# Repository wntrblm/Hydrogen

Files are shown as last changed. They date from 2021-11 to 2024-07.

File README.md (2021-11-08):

# Winterbloom Hydrogen

Hydrogen is a precision buffered multiple for 1U Eurorack.

More details available at https://winterbloom.com/shop/hydrogen

## Repository layout

This repository contains the hardware design files and user guide for Hydrogen:

- **hardware/** contains the hardware design files for the mainboard and blank panel. These are all created using KiCAD.
- **user_guide/** contains the user's guide source files. These are written in Markdown and published using MkDocs.

## License and contributing

Hydrogen is open-source hardware and software, however, licensing a project like this is a little complicated. Please take a chance to review the [LICENSE](LICENSE.md) file.

We welcome contributions! Please read our [Code of Conduct](CODE_OF_CONDUCT.md) first.

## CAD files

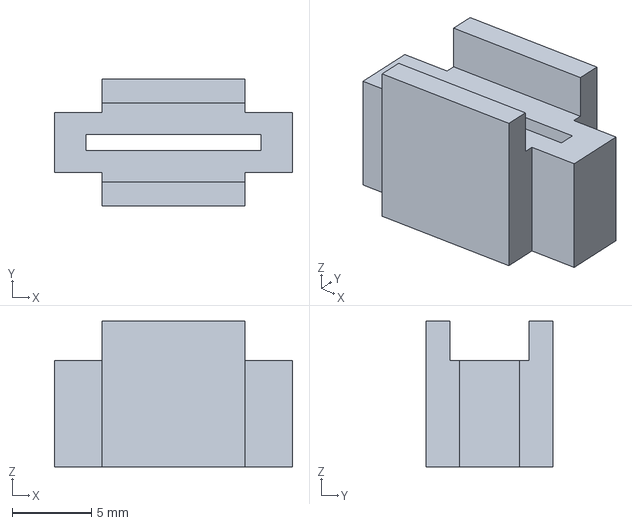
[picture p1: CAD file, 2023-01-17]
hardware/light-guide/light-guide.3mf
15.0 x 8.00 x 9.20 mm

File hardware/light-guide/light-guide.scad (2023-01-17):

difference() {
    linear_extrude(9.2) {
        difference() {
            union() {
                square([15, 3.8], center=true);
                square([9, 8], center=true);
            }
            square([11, 1], center=true);
        }
    }
    translate([0, 0, 9.2-2.5]) {
        linear_extrude(3) {
            square([18, 5], center=true);
        }
    }
}

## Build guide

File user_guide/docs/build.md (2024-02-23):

---
title: Kit build guide
---

# Hydrogen kit build guide

Welcome to the build guide for Hydrogen's DIY kit. We hope you have a great time putting this module together and a wonderful time using it.

Please **read all instructions** thoroughly before starting. If you have questions or run into trouble please reach out to us on [discord] or drop us an email at support@winterbloom.com.

Some soldering experience is helpful but not required. If it's your first time soldering we recommend reading through [Adafruit's guide to excellent soldering](https://learn.adafruit.com/adafruit-guide-excellent-soldering).

This build takes around **one hour** to complete.

[discord]: https://discord.gg/UpfqghQ

## Tools required

Before you begin, make sure that you've got:

-   Safety glasses. Yes, **really**. A pair like [these][safety glasses] are fine.
-   Proper ventilation, like this [small filtered fan](https://a.co/d/eUfPCRO).
-   A **temperature-controlled** soldering iron, like this [Hakko] or the [Pinecil]. It is very important to use a temperature-controlled iron, since unregulated irons can easily get hot enough to damage components. You should set your iron temperature based on your solder manufacturer's recommendations.
-   Solder. We recommend [Adafruit's SAC305 solder][adafruit solder] or [Kester 275 K100LD].
-   A small flat head screwdriver, like [this one][small screwdriver].

!!! question "Flux"
    We suggest using solder with "no clean" flux. If you use a different kind of flux, be sure to carefully clean the flux residue off based on the guidelines provided by the manufacturer of your solder. Take special care with the LEDs and potentiometers, as they can be damaged by water and flux cleaners.

[safety glasses]: https://a.co/d/dMXvPP6
[tweezers]: https://www.adafruit.com/product/422
[Hakko]: https://www.adafruit.com/product/1204
[Pinecil]: https://pine64.com/product/pinecil-smart-mini-portable-soldering-iron/
[adafruit solder]: https://www.adafruit.com/product/734
[Kester 275 K100LD]: https://www.kester.com/products/product/275-flux-cored-wire
[flux pen]: https://www.sra-solder.com/sra-312-no-clean-flux-pen-refillable
[small screwdriver]: https://lovemyswitches.com/2mm-flat-head-screwdriver-for-knob-set-screws/

## Kit contents

Your kit should contain the following items. If any are missing please email us at support@winterbloom.com.

<winter-image-map src="../images/kit.svg">
    <winter-image-map-item id="mainboard">Mainboard</winter-image-map-item>
    <winter-image-map-item id="panel">Front panel</winter-image-map-item>
    <winter-image-map-item id="jacks">1/8" jacks (10)</winter-image-map-item>
    <winter-image-map-item id="nuts">Hex nuts for the 1/8" jacks (10)</winter-image-map-item>
    <winter-image-map-item id="power-header">Eurorack power header (1)</winter-image-map-item>
    <winter-image-map-item id="rubber-bands">Rubber bands (2)</winter-image-map-item>
    <winter-image-map-item id="light-blocker">Light blocker</winter-image-map-item>
</winter-image-map>

- (1) Mainboard
- (1) Front panel
- (10) 1/8" jacks
- (10) Hex nuts for the 1/8" jacks
- (1) Eurorack power header
- (2) Rubber bands
- (1) Light blocker

!!! fairy "Light blocker"
    Older kits include a little plastic square for the light blocker along with a glue dot, newer kits include a 3d-printed light blocker. The older one is pictured here.

## Soldering the power header

Your first task is to place and solder the power header to the mainboard.

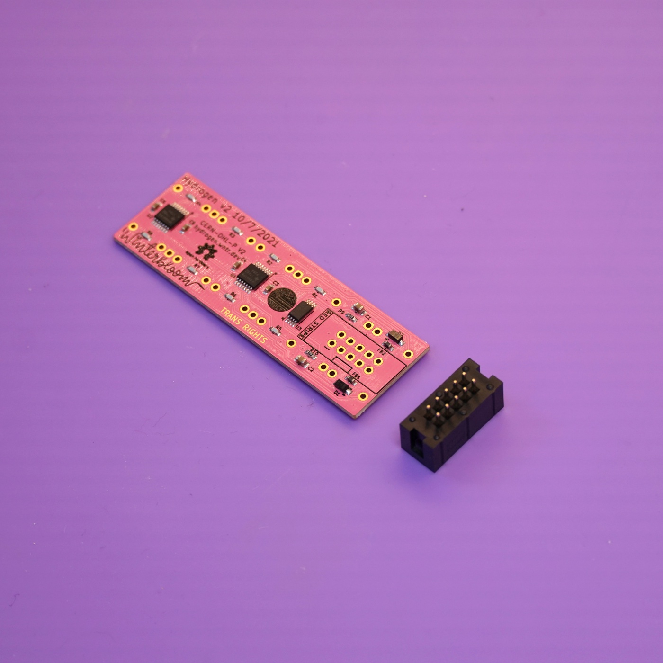
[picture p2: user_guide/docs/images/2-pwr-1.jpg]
The mainboard and power header


Place the power header onto the back side of the mainboard, being careful to align the notch in the header with the drawing on the board. The power header fits snugly, so you might have to give it a little pressure to push it all the way in.

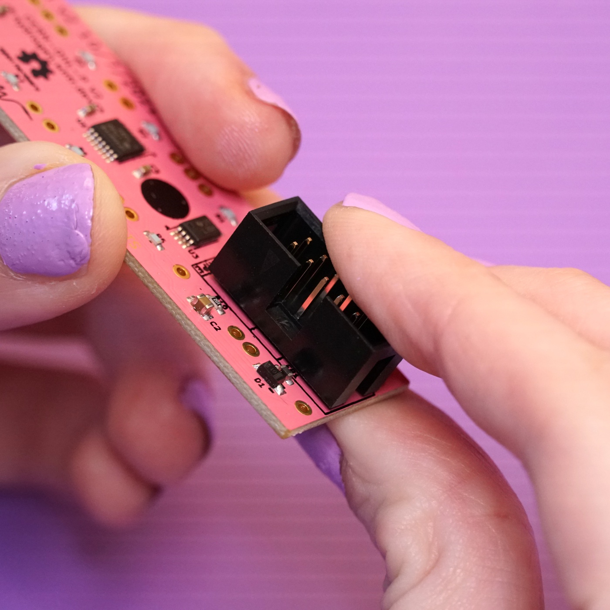
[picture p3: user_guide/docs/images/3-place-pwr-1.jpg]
The power header placed on to the mainboard


Flip the board over to the front side and solder the header's 10 pins. It's important to **avoid touching the LEDs** with your iron, as it could melt and destroy the LEDs. Also, take care not to put too much solder on these joints as it could make it difficult to place the jacks.

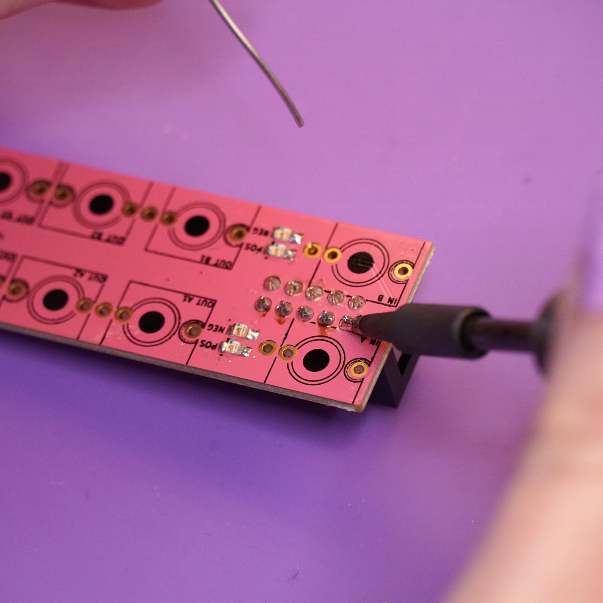
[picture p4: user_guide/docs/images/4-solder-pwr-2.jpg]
The power header being soldered to the mainboard


## Placing the jacks

Next up is placing the ten jacks on the front side of the mainboard.

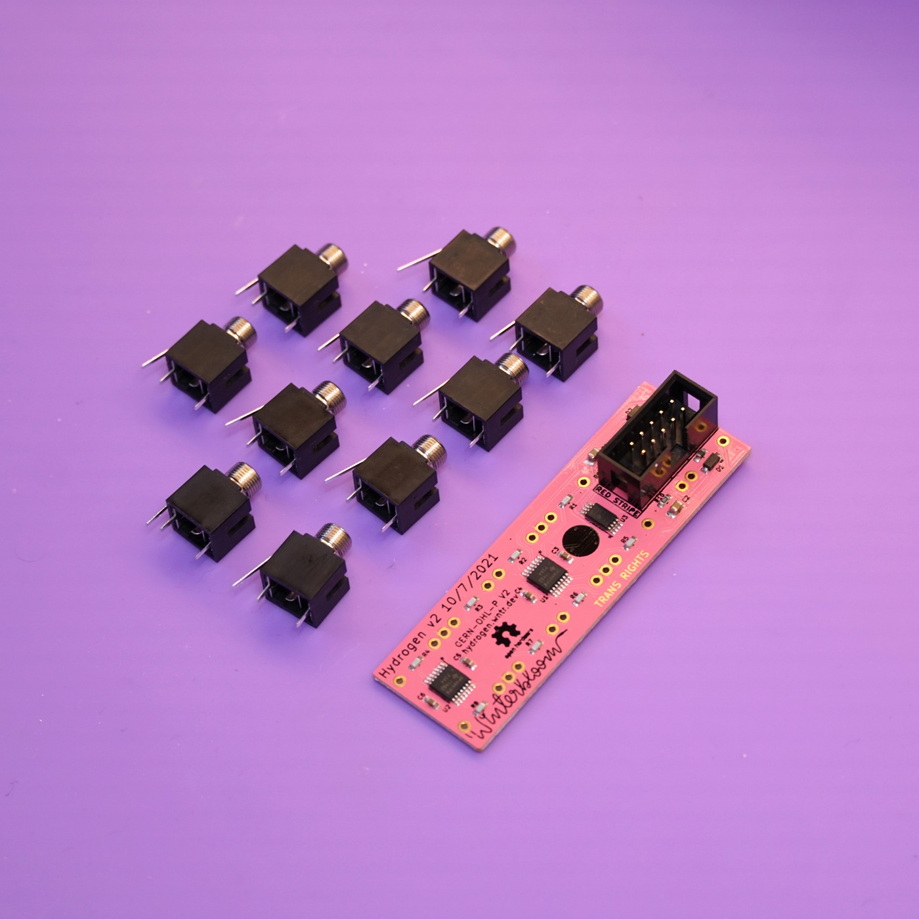
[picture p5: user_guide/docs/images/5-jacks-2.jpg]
The jacks and the mainboard


The two jacks near the power header are placed according to the drawing on the board, with the third, bendy leg going into the adjacent hole.

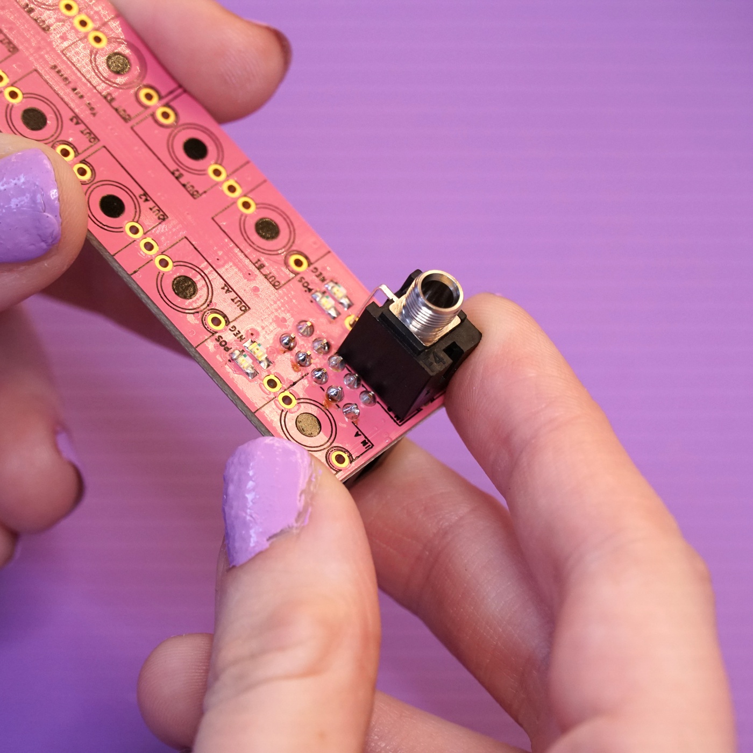
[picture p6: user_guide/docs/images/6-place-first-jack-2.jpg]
The first jack placed on the front side of the mainboard, over the place labeled "In B"


The other jacks are a bit trickier. Start by placing the jack for `Out B1` in the **same** orientation as the first two.

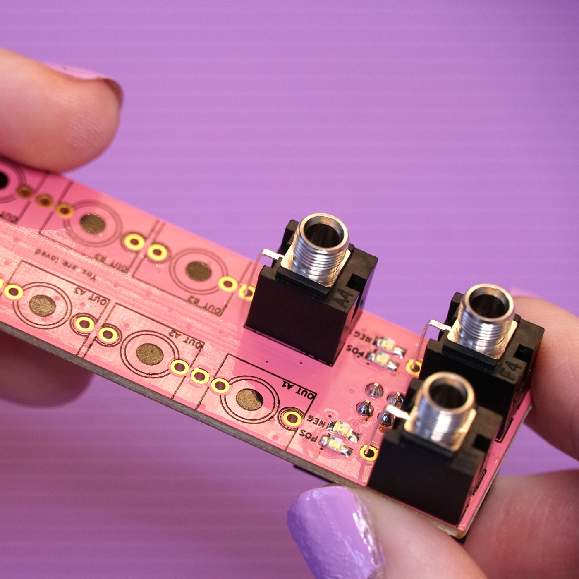
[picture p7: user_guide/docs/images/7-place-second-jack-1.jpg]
The third jack placed on the front side of the mainboard, over the place labeled "Out B1"


Then, place the jack for `Out B2` in the **opposite** orientation and place the third leg into the **same** hole as the adjacent jack's third leg.

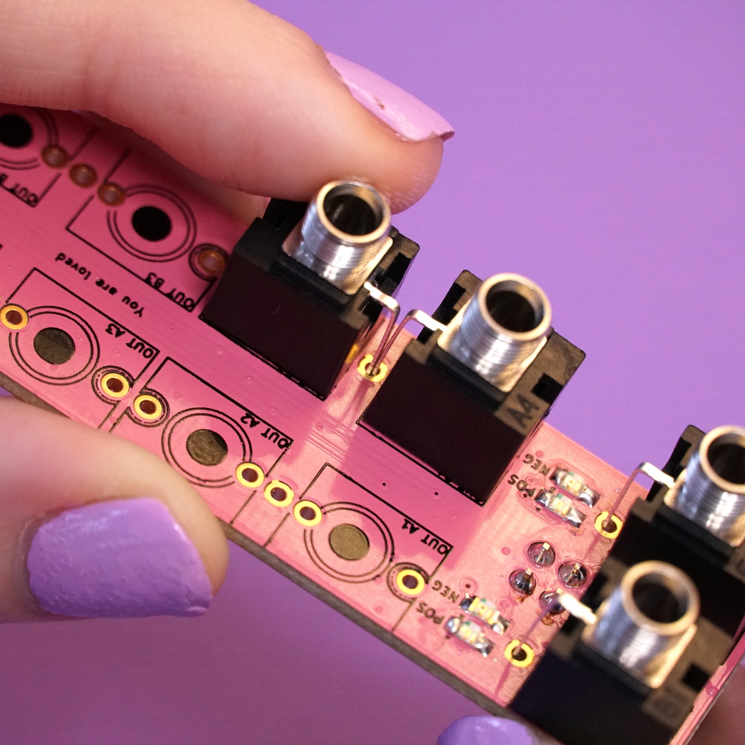
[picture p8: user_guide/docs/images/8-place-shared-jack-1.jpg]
The fourth jack placed on the front side of the mainboard, over the place labeled "Out B2". It is facing the opposite direction of the "Out B1" jack and is sharing a hole with it


The jacks for `Out B3` and `Out B4` follow the same pattern - they are placed in opposite orientations and share a single hole for both of their third legs.

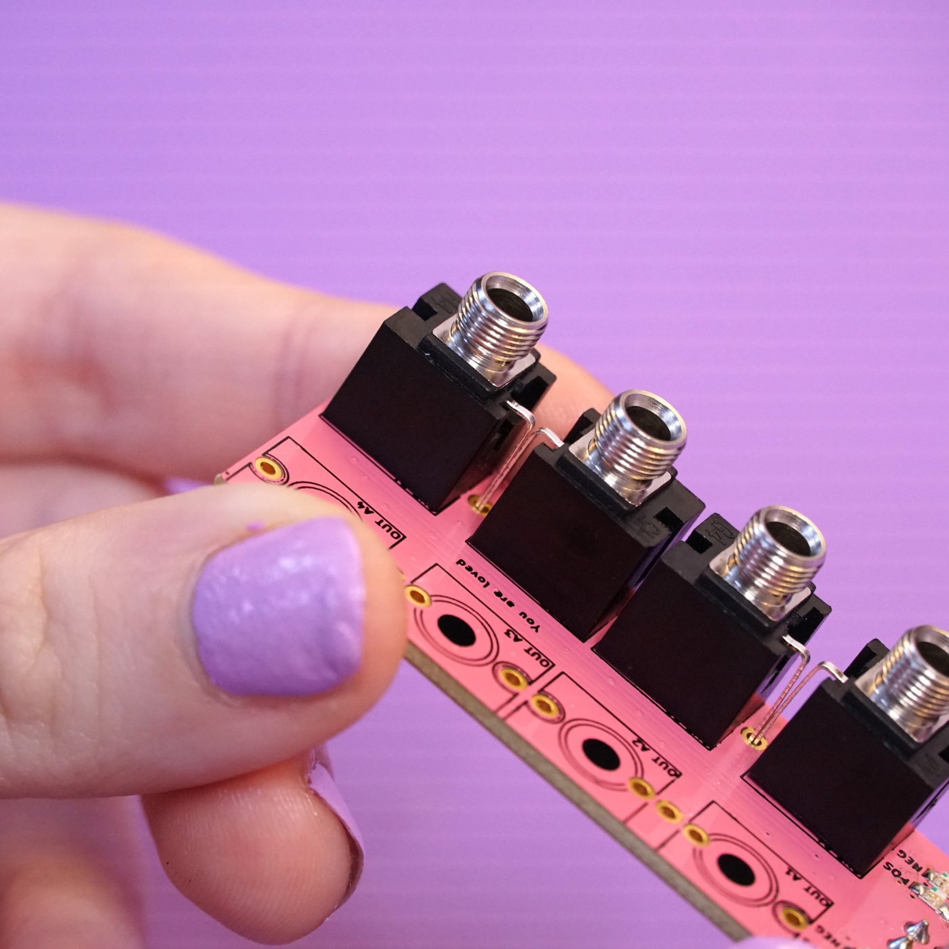
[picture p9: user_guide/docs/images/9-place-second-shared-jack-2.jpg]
The fifth and sixth jack placed on the front side of the mainboard over the places labeled "Out B3" and "Out B4" and are placed in the same way as the previous two


Repeat the same process to place the jacks for outs `A1`, `A2`, `A3`, and `A4`.

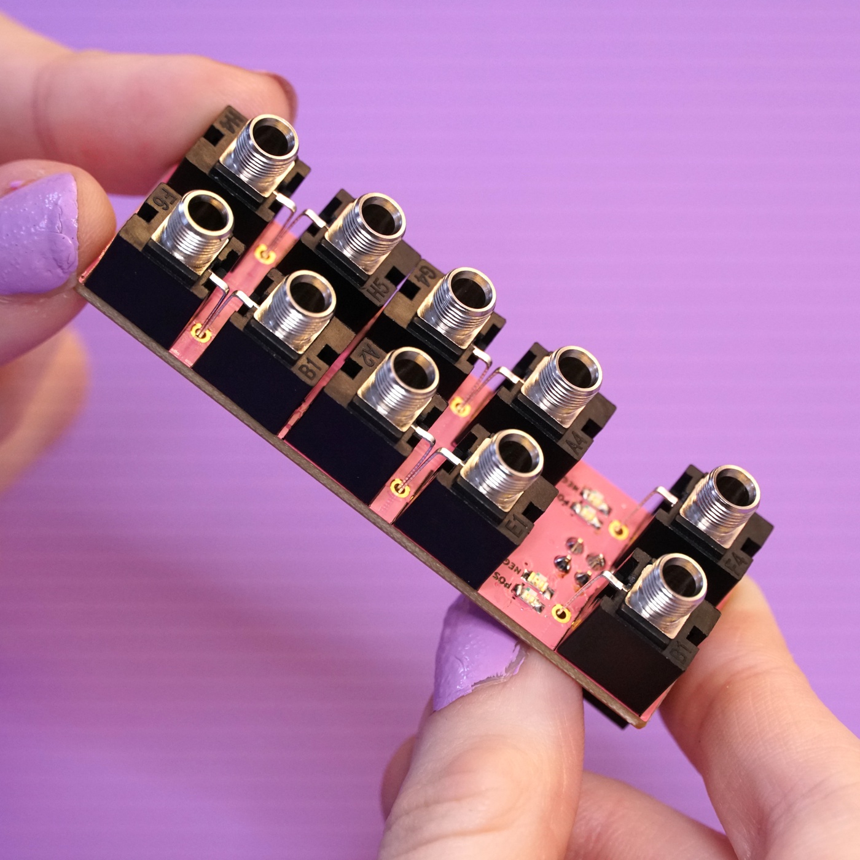
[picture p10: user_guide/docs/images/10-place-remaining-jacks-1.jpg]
The remaining jacks placed in the same way as the previous ones


## Using the front panel as a jig

Since the jacks need to peek through the front panel, you can use it as a jig to make sure everything stays in the right place while soldering. Carefully line up the front panel's holes with the jacks and push the front panel on. Then, use the two rubber bands to temporarily hold the front panel on while you're working on it. You'll need to double over the rubber band to get it tight. Put the other rubber bands on the opposite side of the module so that everything is held down snugly.

<winter-carousel>
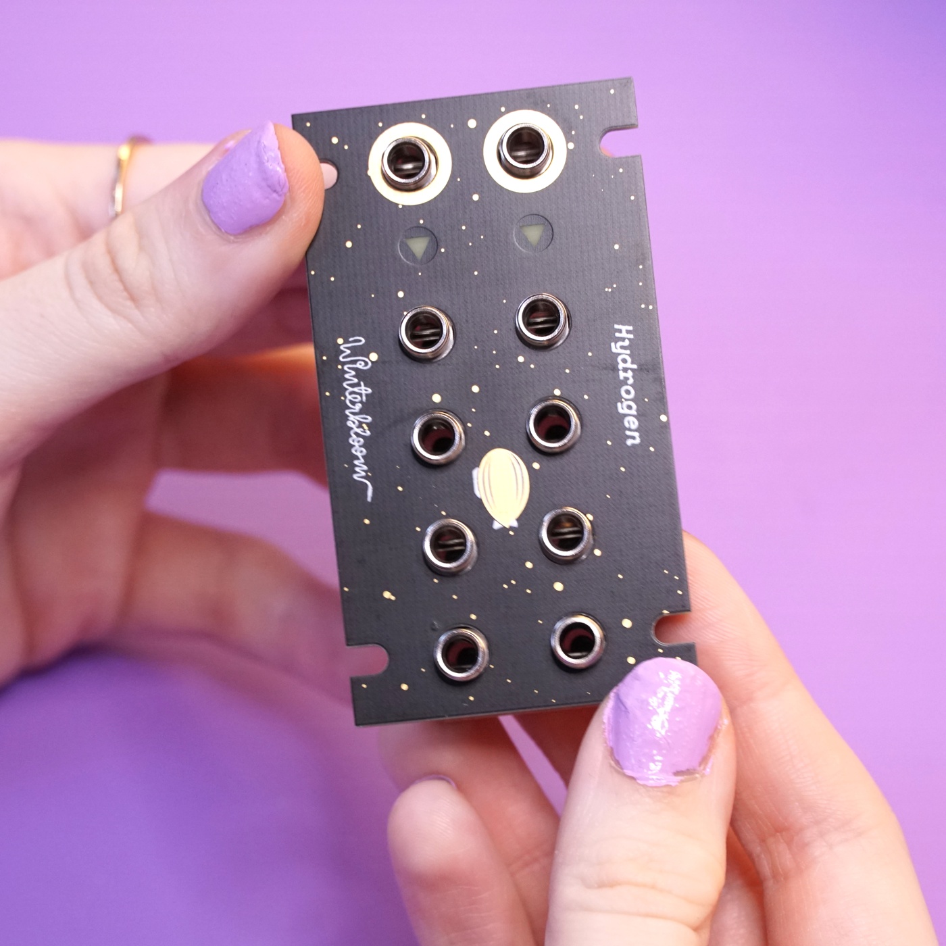
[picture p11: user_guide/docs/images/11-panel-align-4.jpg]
The front panel placed over the jacks
    
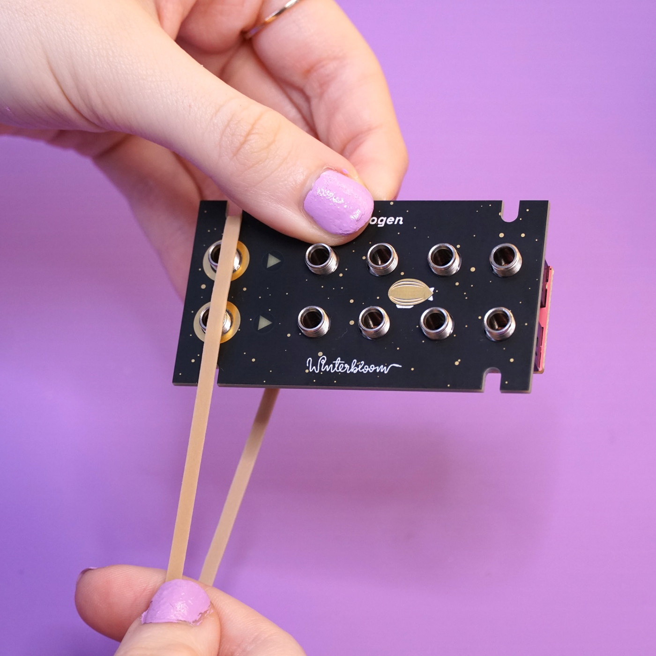
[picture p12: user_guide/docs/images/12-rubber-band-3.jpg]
A rubber band being pulled taught over one side of the module
    
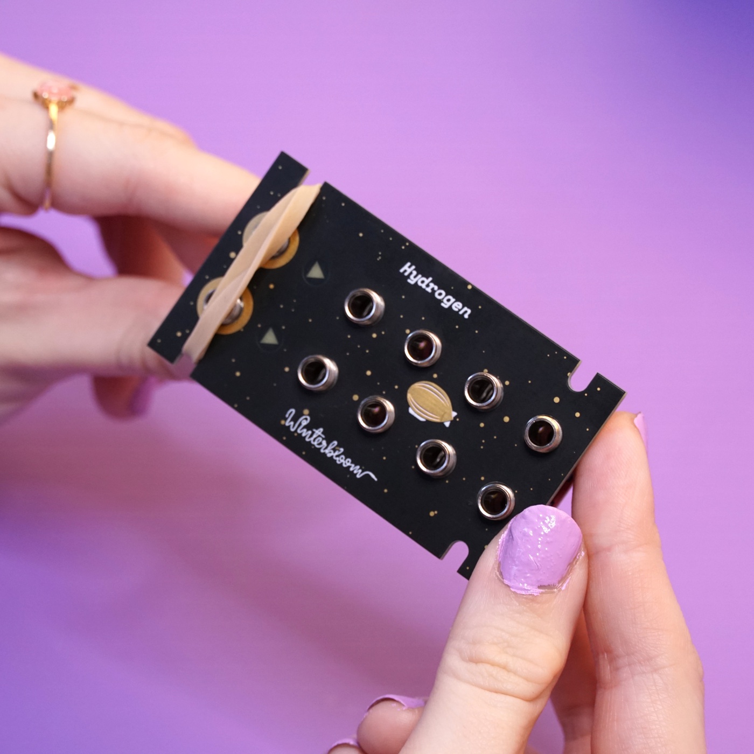
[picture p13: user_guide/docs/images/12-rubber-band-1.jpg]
The same rubber band doubled over and holding the front panel onto the module
    
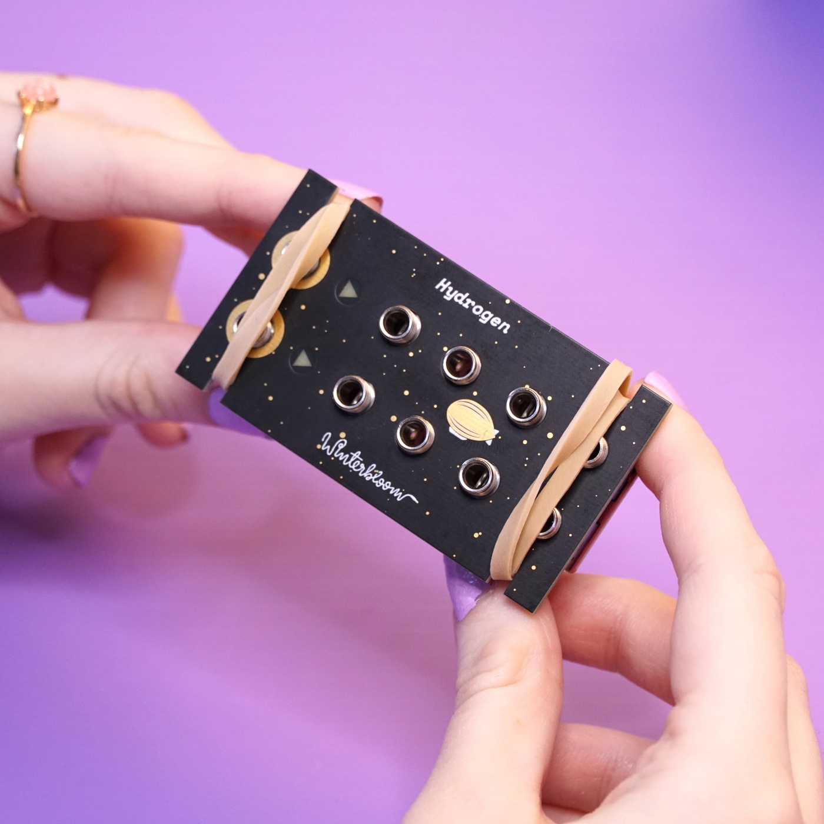
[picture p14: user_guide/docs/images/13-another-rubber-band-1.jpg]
Another rubber band has been placed on the other side of the module, firmly holding everything together
    
</winter-carousel>

## Soldering the jacks

With everything held in place, you can now flip the module over and solder all of the jacks in place. As you go, take a moment now and then to check that everything is flush with the panel and mainboard.

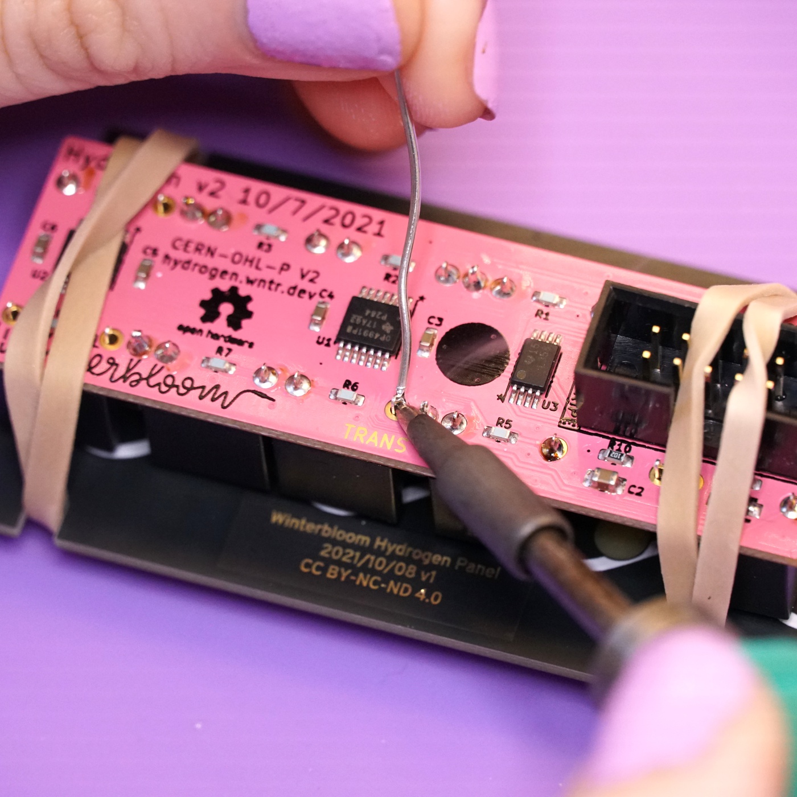
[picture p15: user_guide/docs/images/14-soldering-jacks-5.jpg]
The back side of the board is shown where one of the holes for the jacks is being soldered


Once you've got most of the soldering done, you can move the rubber bands out of the way to get to the holes that they were covering up. You won't need the rubber bands again after this step, so feel free to give those a new purpose in life somewhere else.

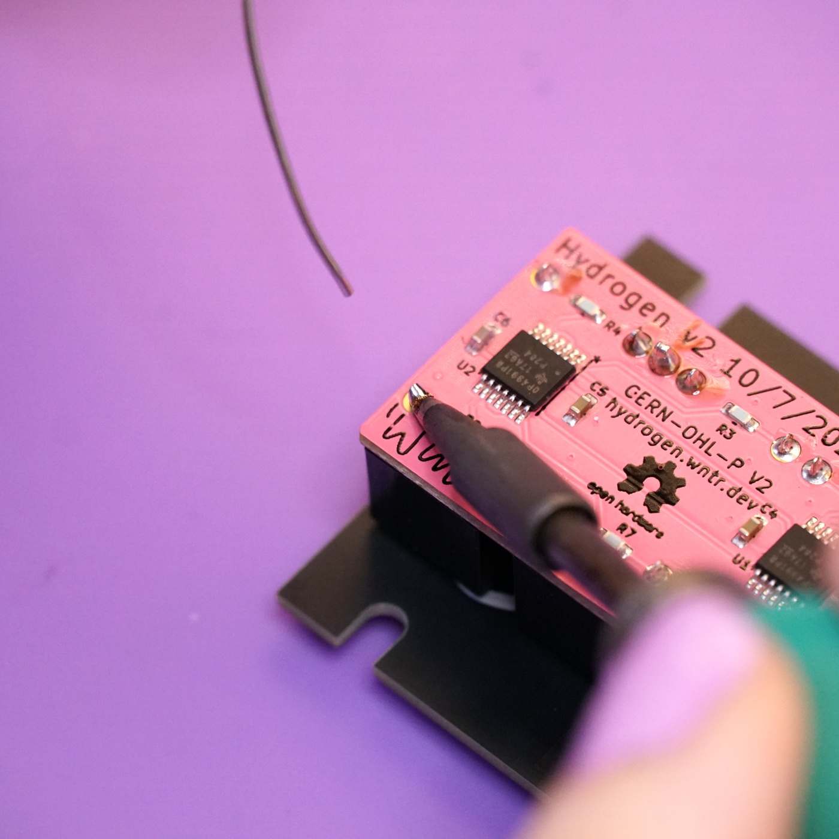
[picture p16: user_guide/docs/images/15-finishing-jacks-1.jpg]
The back side of the board is shown with the last hole for the jacks being soldered


## Placing the light blocker

Because the LEDs for Hydrogen's two channels are so close together, a small light blocker is used to keep them from bleeding into each other. There are **two versions** of the light blocker out there:

* The **older** kits come with a simple plastic square and a glue dot. The instructions below are for this version.
* The **newer** kits come with a 3d-printed light blocker. You don't need to glue this one in place, just place it in-between the jacks with the **flat side** facing upwards. The faceplate will hold it in place.

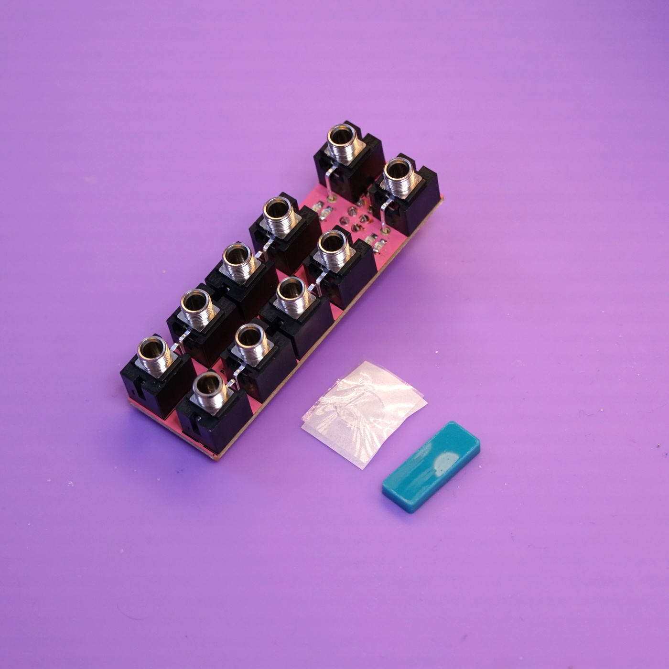
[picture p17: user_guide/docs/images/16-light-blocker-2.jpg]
The mainboard, the glue dot, and the light blocker


Prepare the glue dot by peeling off the white paper. Don't remove the clear film yet.

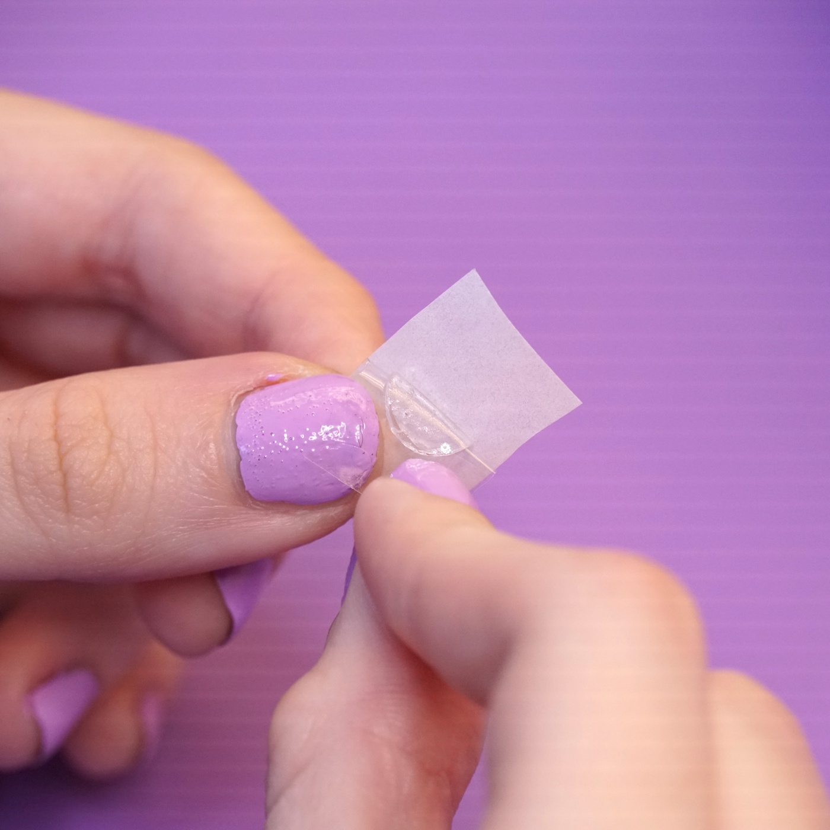
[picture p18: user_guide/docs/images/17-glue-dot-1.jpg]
The glue dot being peeled away from the white paper on one side of it


Place the exposed side of the glue dot to the upper end of the long side of the light blocker and remove the plastic film.

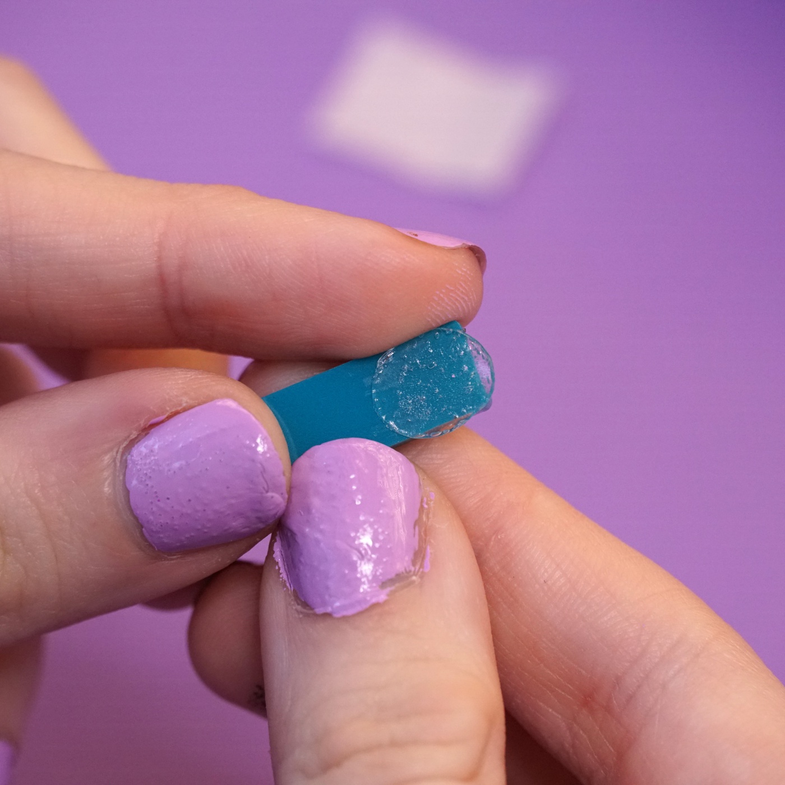
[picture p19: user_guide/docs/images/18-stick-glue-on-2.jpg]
The light blocker with the glue dot attached to one side of it


Place the light blocker between the two sets of LEDs and stick the end with the glue dot against one of the jacks. The light blocker doesn't need to be perfectly straight.

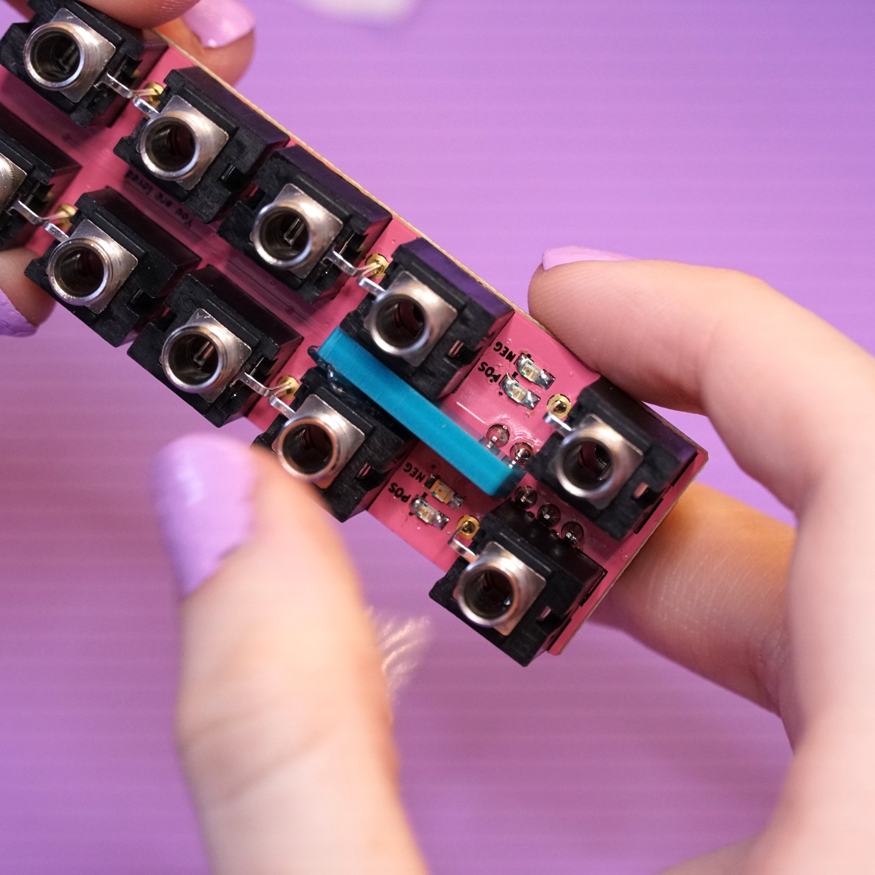
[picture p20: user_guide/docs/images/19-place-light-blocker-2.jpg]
The front side of the mainboard with the light blocker placed between the two sets of LEDs


## Putting the panel on

The last step it to place Hydrogen's lovely panel on and secure it with the hex nuts. You don't need to over-tighten the hex nuts, finger-tight is fine.

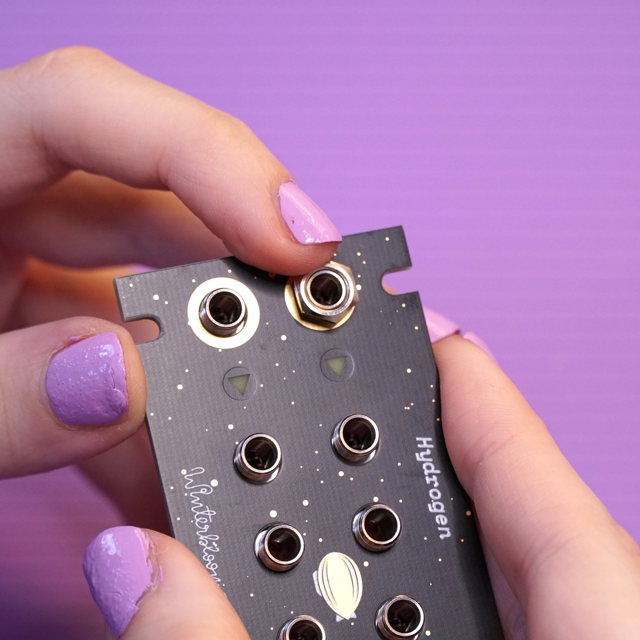
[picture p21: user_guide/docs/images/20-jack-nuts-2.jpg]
The module with the panel placed and one of the jack nuts being tightened in place


## All done

Congratulations! You've finished your very own Hydrogen!

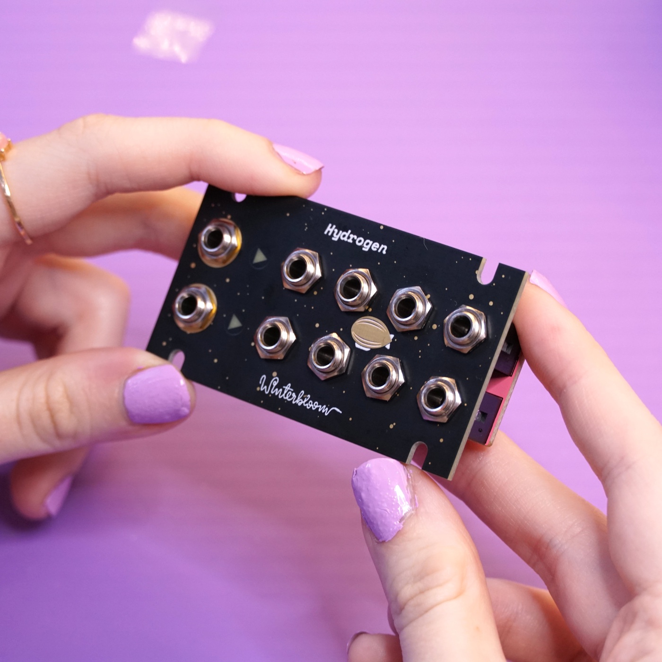
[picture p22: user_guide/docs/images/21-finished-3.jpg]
The compeleted module


Now that it's all put together go check out the [User's Guide](index.md) and please show us your work by tweeting at [@wntrblm](https://twitter.com/wntrblm) or tagging [@wntrblm](https://instagram.com/wntrblm) in your instagram post.

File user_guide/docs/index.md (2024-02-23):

# Hydrogen user guide

[Hydrogen](https://winterbloom.com/shop/hydrogen) is a 1U precision, two channel, 1-to-4 buffered multiple.

[TOC]

## Specifications

* Available [assembled](https://winterbloom.com/shop/hydrogen) or as a [kit](https://winterbloom.com/shop/hydrogen-kit)
* `1U` & `14 HP`
* `+12v @ 20mA`, `-12v @ 20mA`
* `22mm` deep
* Two channels
* Each channel has four buffered outputs
* Second channel normaled to the first so it can be used as a 1-to-8 buffered multiple.
* [ModularGrid page](https://www.modulargrid.net/e/winterbloom-hydrogen)

## Getting support and help

We want you to have a wonderful experience with your module. If you need help or run into problems, please reach out to us. [Email] is the best way for product issues, whereas [Discord] and [GitHub][github issues] are great for getting advice and help on how to customize your module.

-   Send us [an email][email]
-   File a bug [on GitHub][github issues]
-   Reach out on the [Discord][discord]

[github issues]: https://github.com/wntrblm/Neptune/issues
[discord]: https://discord.gg/UpfqghQ
[email]: mailto:support@winterbloom.com

## Installing the module

To install this into your Eurorack setup, connect a Eurorack power cable from your power supply to the back of the module. **Note that even though there's a keyed power connector on the module, double check that the red stripe is on the side labeled `red stripe`!** Once you've connected the power cable, secure your module to your rack rails using screws.

## Using the module

Hydrogen has two independent channels with four buffers. Each channel's input is on the left and the four buffered outputs follow on the right. The LEDs in between will glow blue for positive signals, red for negative signals, and purple for audio signals.

Illustration of using Hydrogen's two channels independently

Additionally, if nothing is connected to the second channel's input then the first channel's input is used. This allows you to use Hydrogen as a single channel one-to-eight buffer.

Illustration of using Hydrogen as a single channel, eight output buffer

That's pretty much it! ✨

## Open source hardware & software

Hydrogen is completely open source and hacking is encouraged.

The [hardware designs](https://github.com/wntrblm/Hydrogen/tree/main/hardware) are available under the permissive [CERN-OHL-P v2](https://cern-ohl.web.cern.ch/) and is designed using [KiCAD](https://kicad.org/) which is free and open-source. You can open the hardware files using KiCAD or you can [check out a PDF of the schematic](https://github.com/wntrblm/Hydrogen/tree/main/hardware/board/board.pdf).

Open Source Hardware Association mark Helium is [certified open source hardware](https://certification.oshwa.org/us002070.html)

## Warranty, disclaimers, and limits

Modules purchased from Winterbloom have a warranty of six months from the date of purchase. This warranty covers any manufacturing defects in the module. It does not cover damage from due to incorrect handling, storage, or power, overvoltage events, or modifications.

Please [contact us](mailto:support@winterbloom.com) if you are experiencing issues with your module. Modules returned under warranty will either be refunded, replaced, or repaired at our discretion. You will be responsible for the cost of returning the module to Winterbloom.

Because Eurorack has a vast number of possible combinations of power supplies, modules, cases, and accessories, it is impossible for us to guarantee compatibility with every possible configuration. We make a reasonable effort to test modules with several power supplies, cases, and other modules.

We encourage tinkering, however, we will not refund, repair, or replace any products that have been modified.

We have stress tested Hydrogen under the following conditions. These are provided for reference only; we do not guarantee that that the module will function under these conditions.

* Continuous run time: at least 48 hours
* Overvoltage from power supply: at least `±18 volts`
* Reverse voltage from power supply: at least `±18 volts`
* Undervoltage from power supply: as low as `±6 volts`
* Over and under voltage on inputs: at least `±12 volts`
* Outputs shorted together: at least 30 minutes
* Outputs shorted to ground: at least 30 minutes

## Acknowledgments and thanks

Hydrogen would not be possible without the support of Winterbloom's incredible community, the Trans Synth Discord, and Noise Engineering.

[discord]: https://discord.gg/UpfqghQ

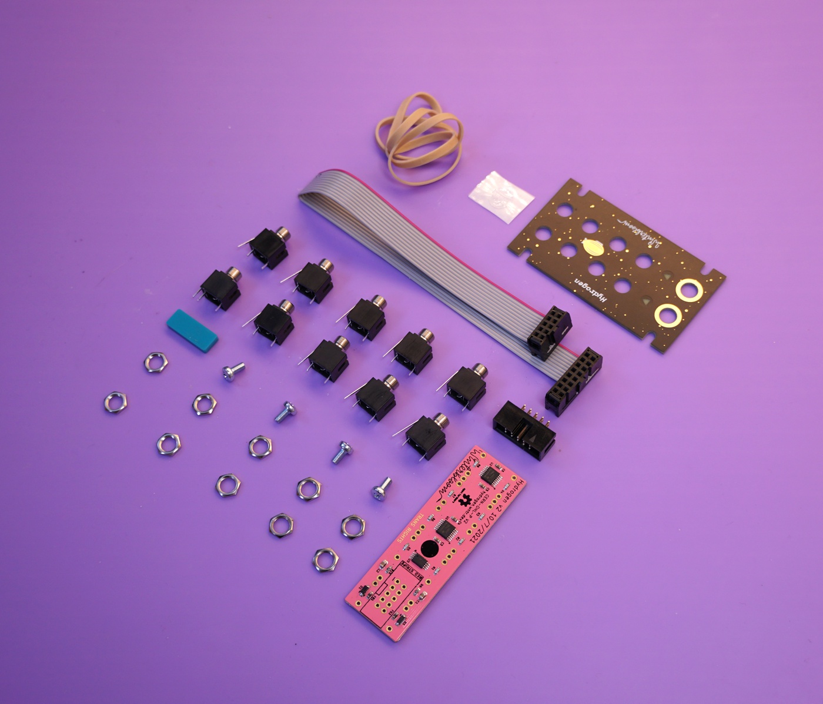
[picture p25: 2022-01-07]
user_guide/docs/images/1-kit-1.jpg

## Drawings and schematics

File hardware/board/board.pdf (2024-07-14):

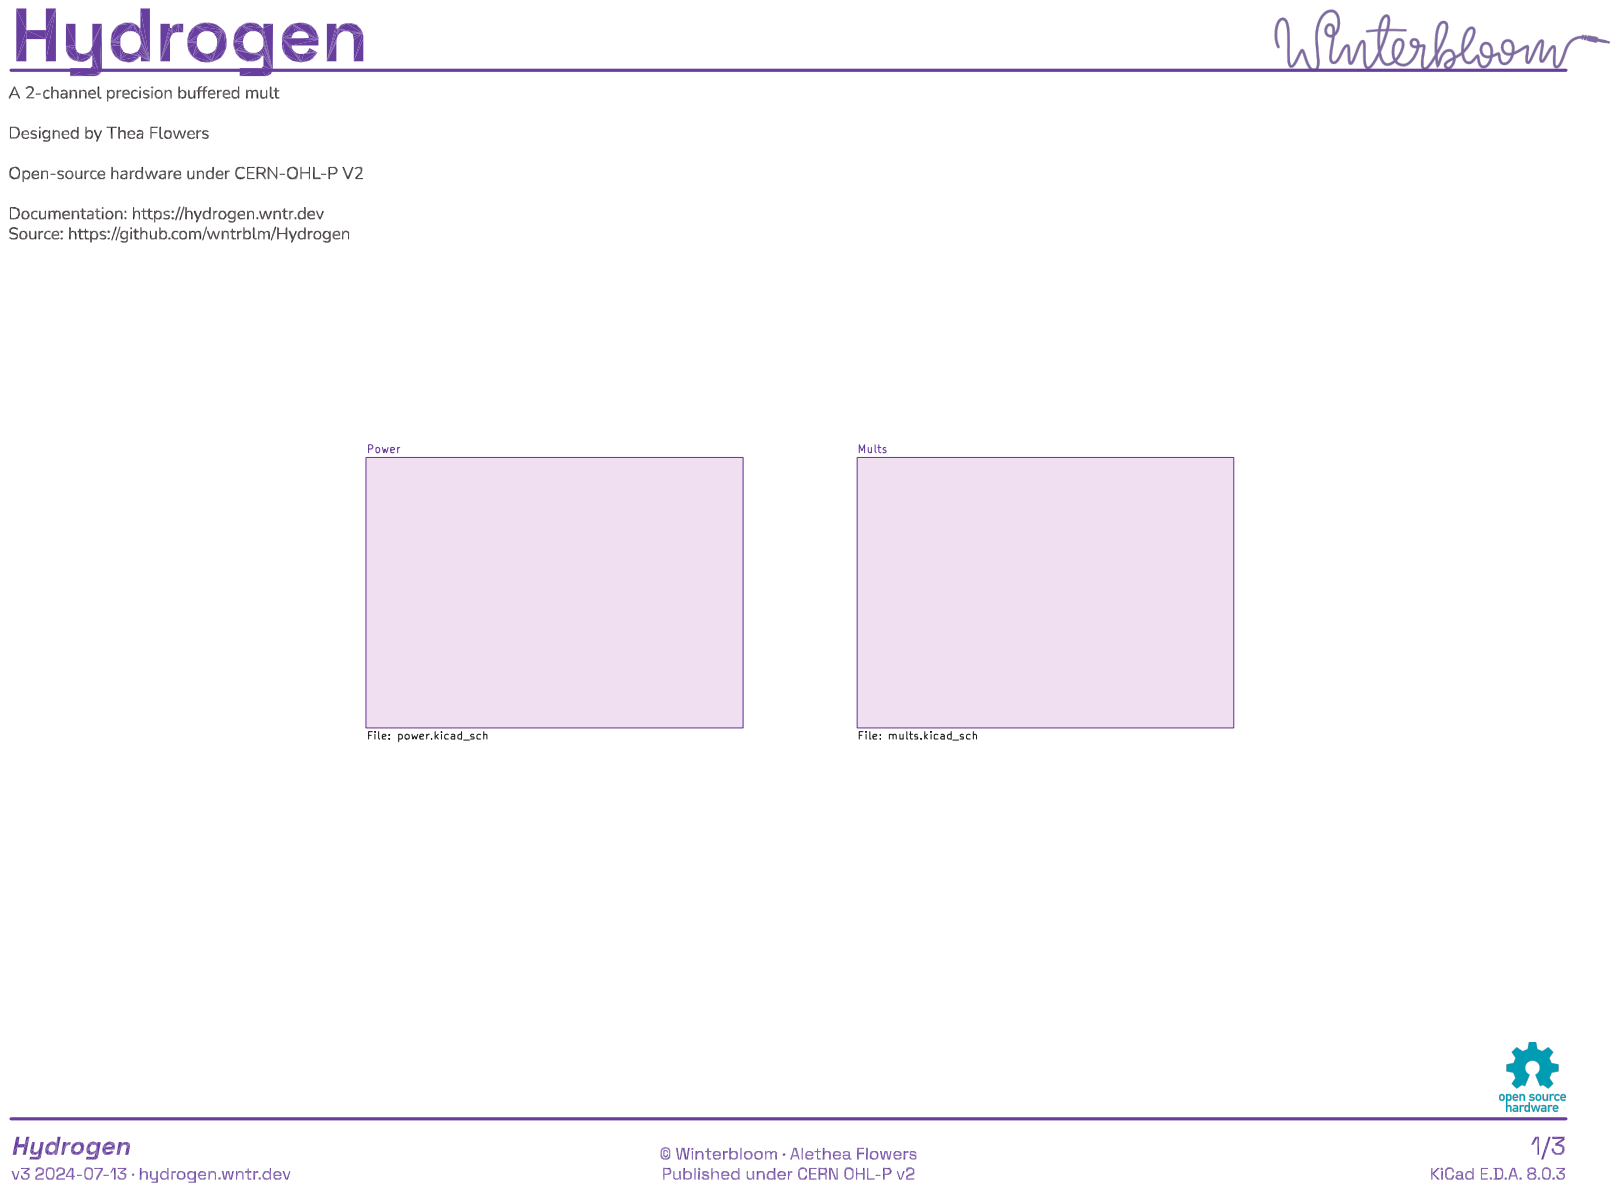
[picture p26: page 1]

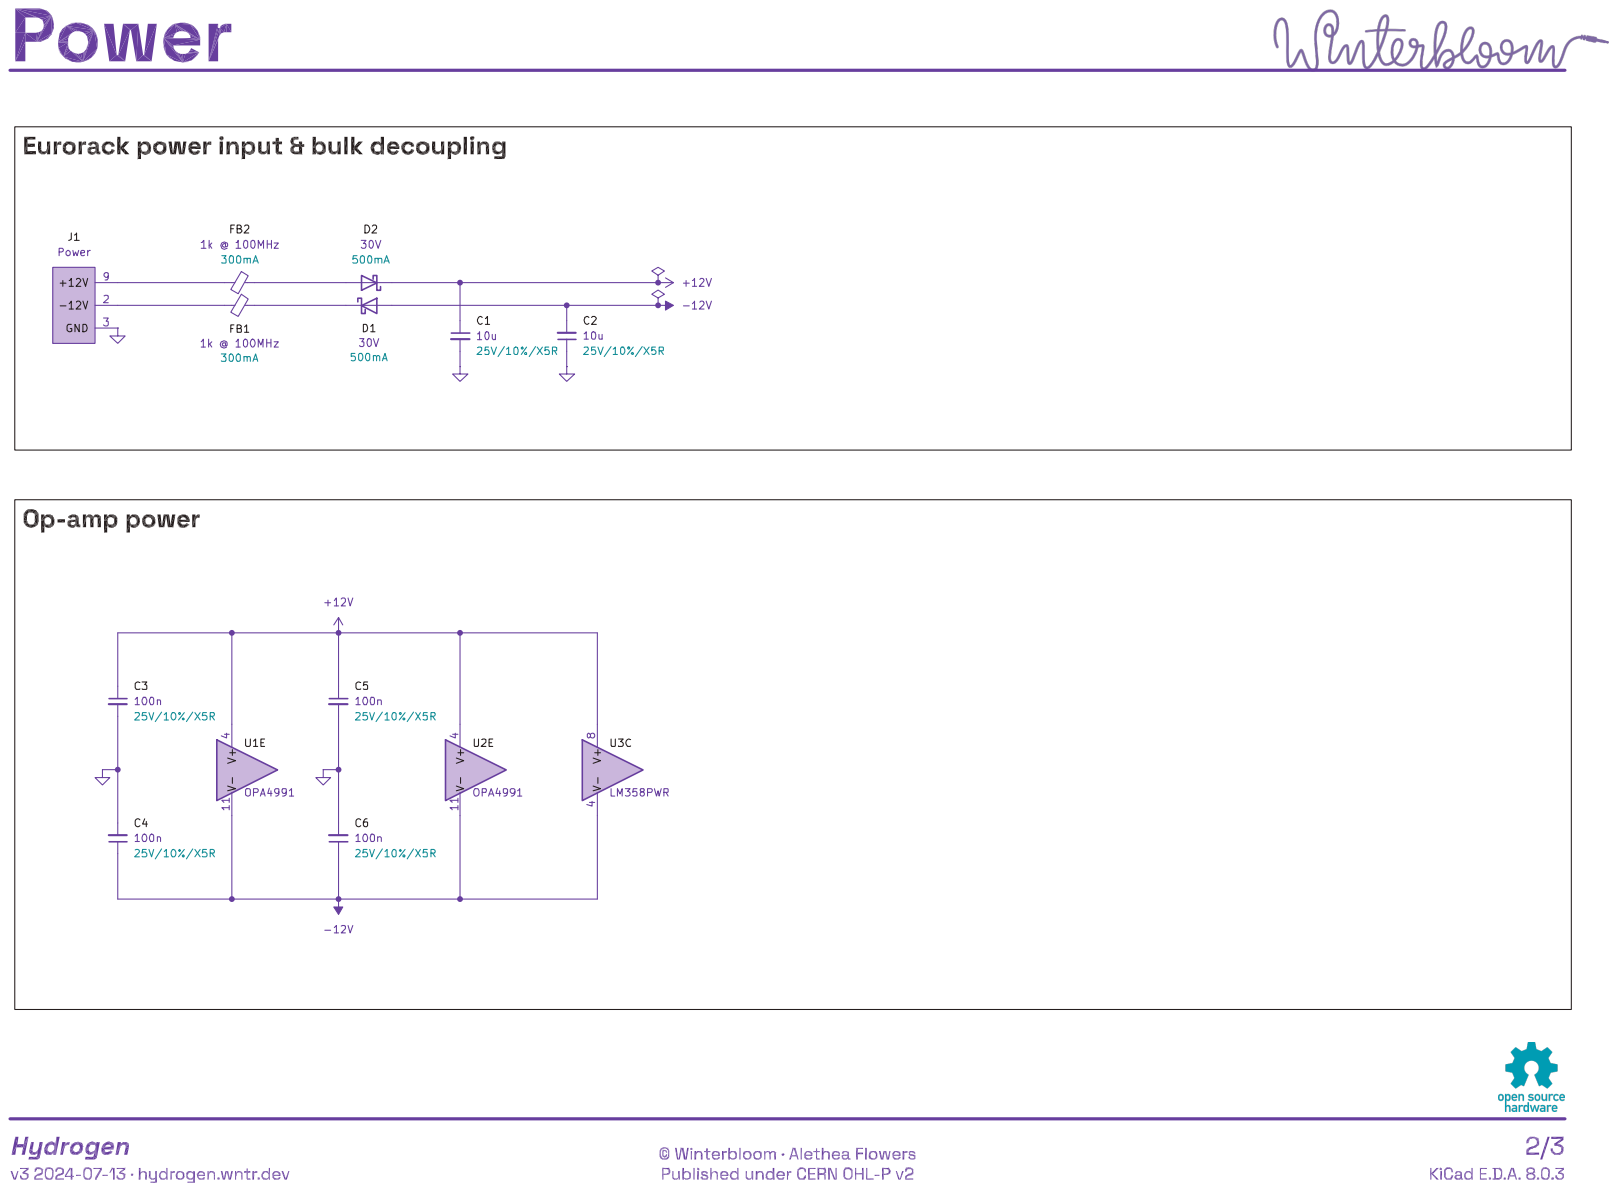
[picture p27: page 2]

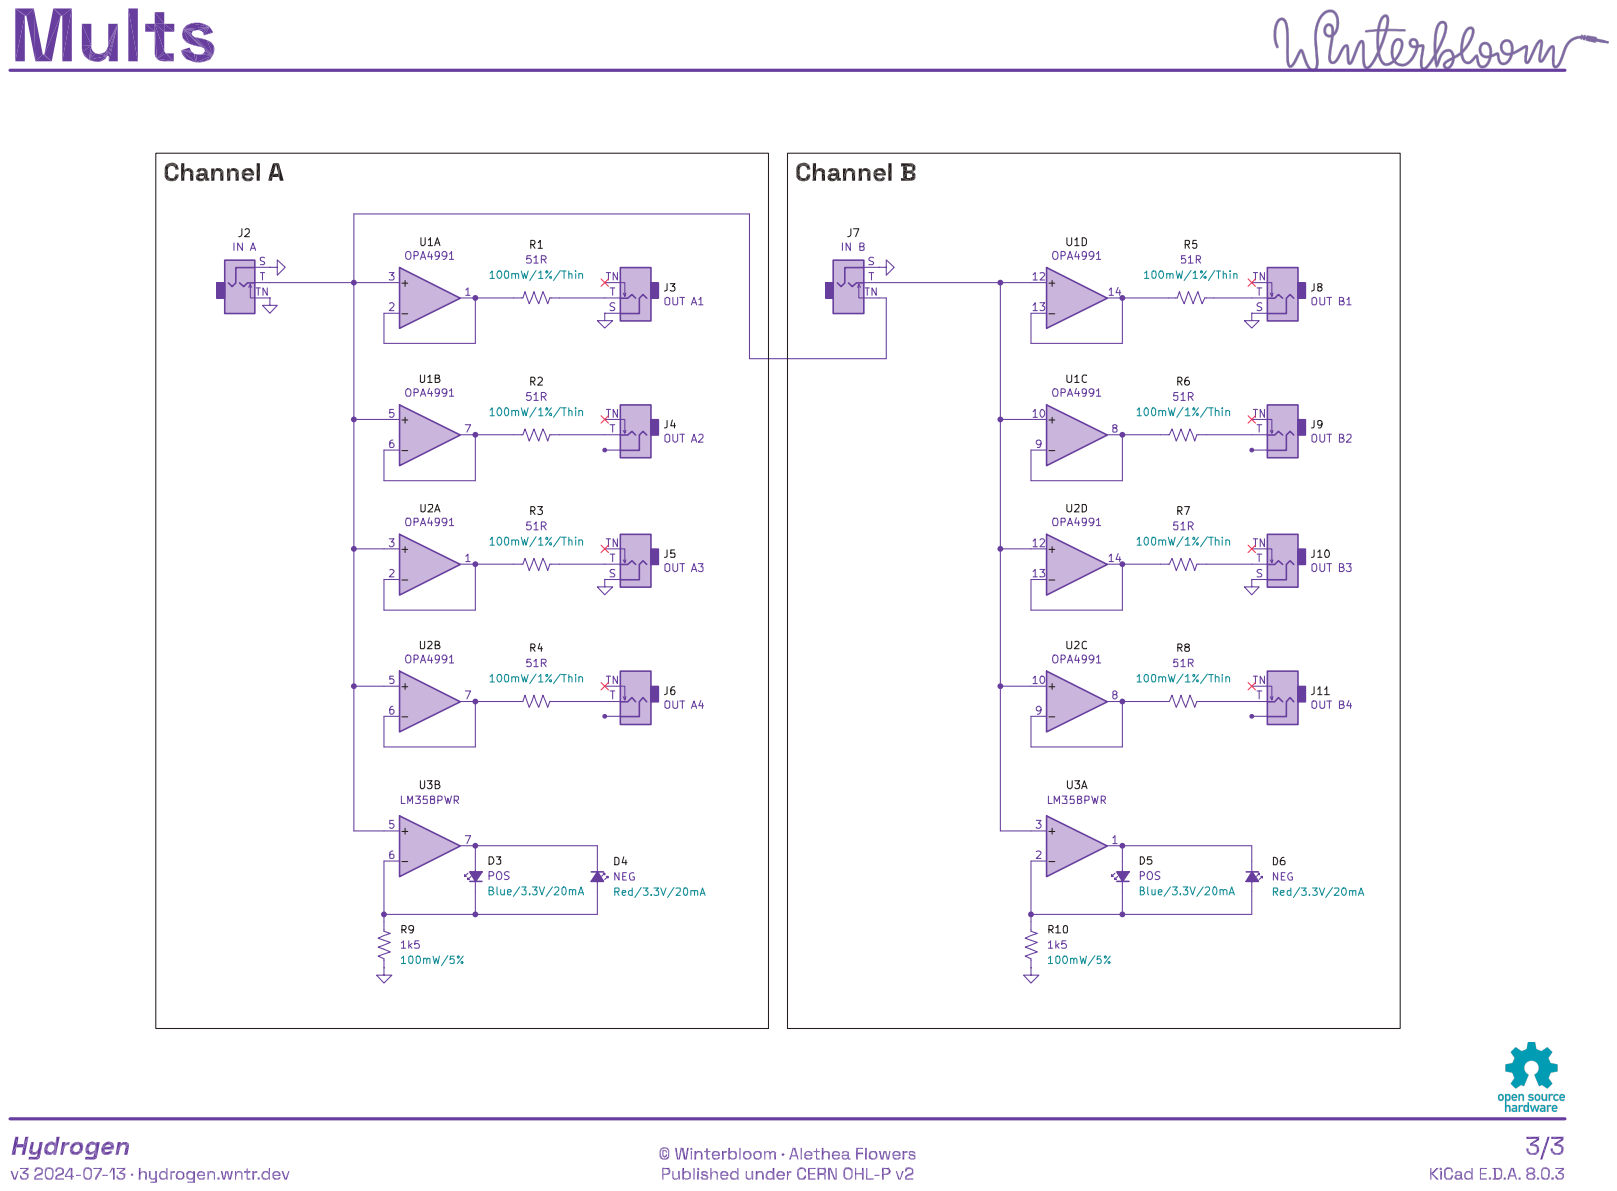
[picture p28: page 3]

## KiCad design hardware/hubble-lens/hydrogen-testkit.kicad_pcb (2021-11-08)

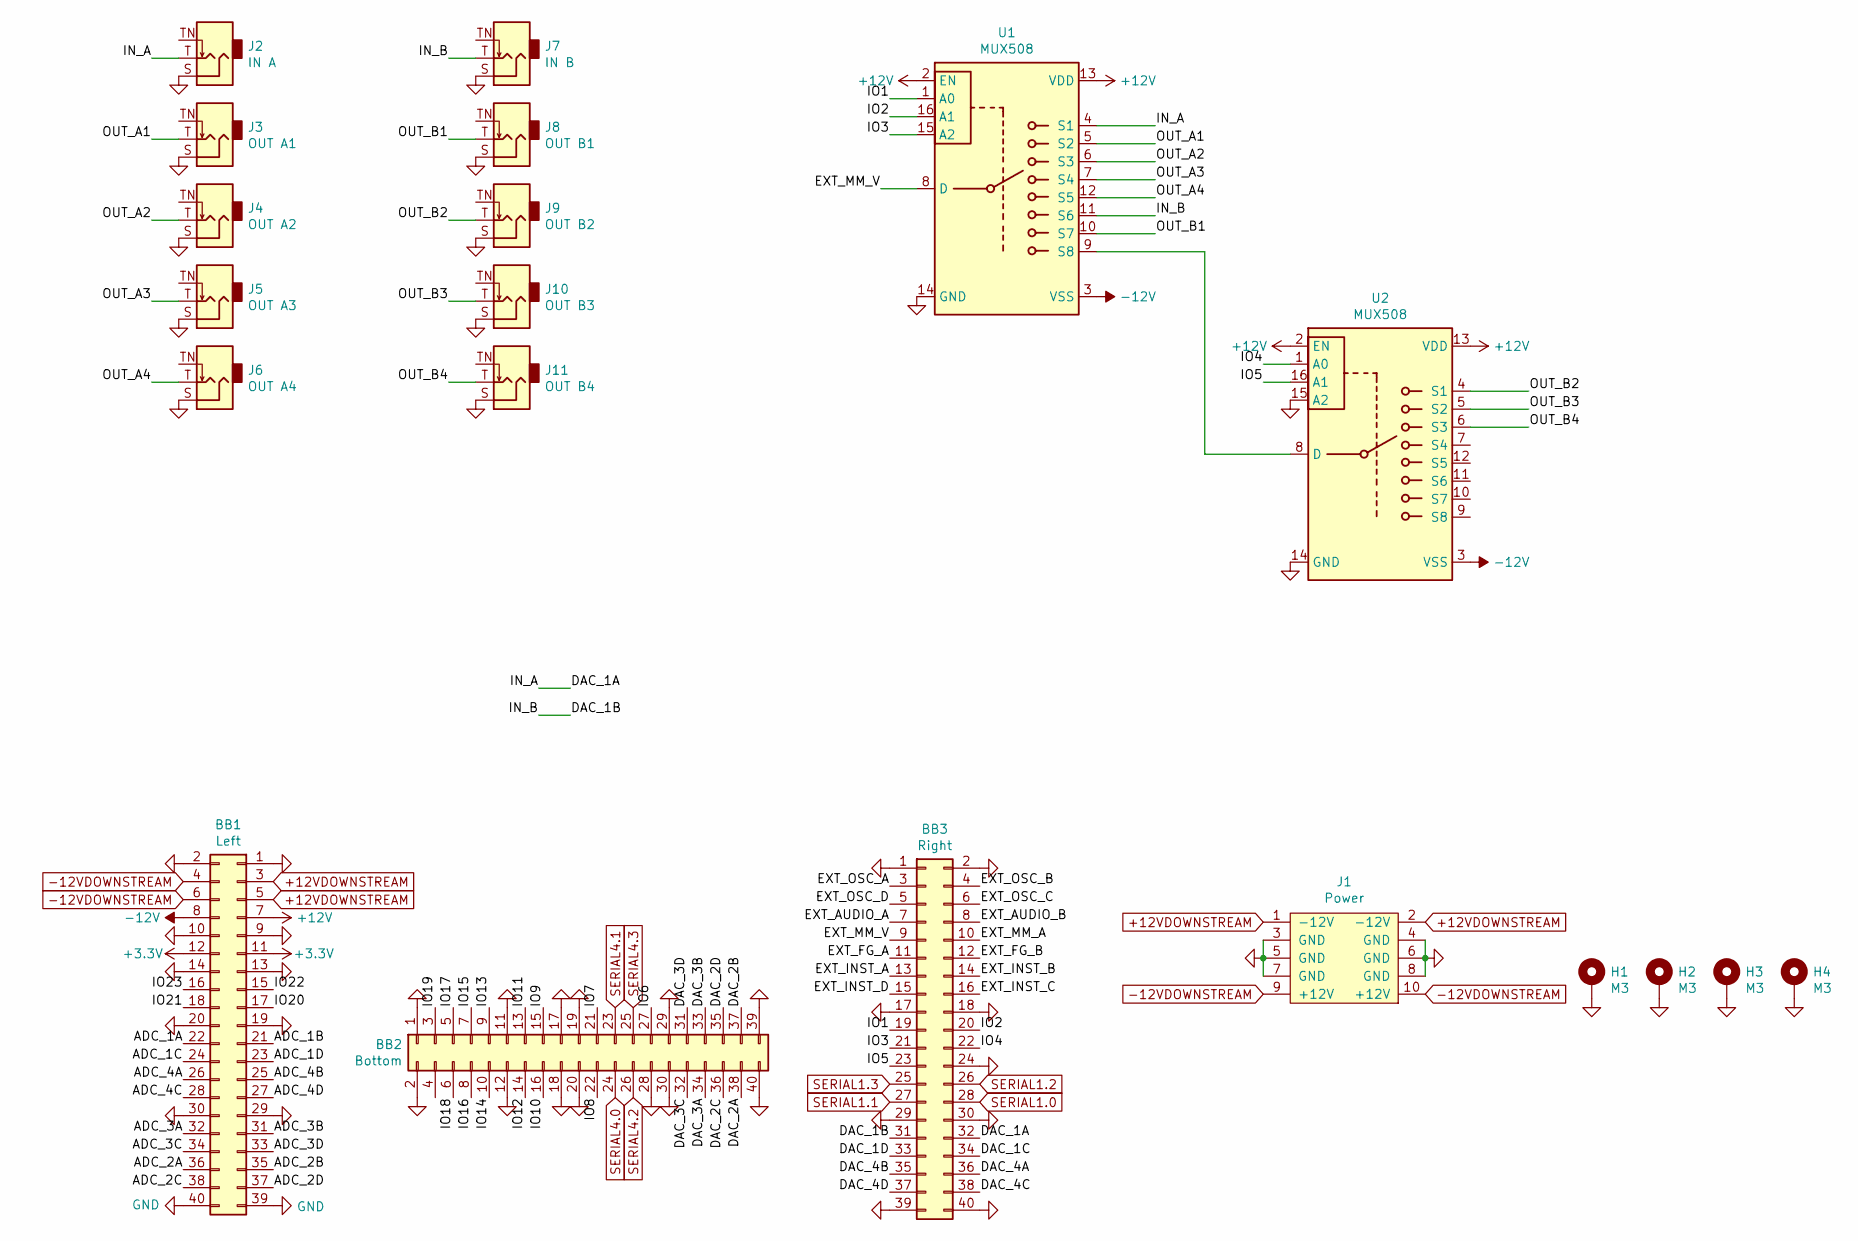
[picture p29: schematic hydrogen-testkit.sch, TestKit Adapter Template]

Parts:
BB1: Left; PinSocket_2x20_P2.54mm_Vertical
BB2: Bottom; PinSocket_2x20_P2.54mm_Vertical
BB3: Right; PinSocket_2x20_P2.54mm_Vertical
H1, H2, H3, H4: M3; MountingHole_3.2mm_M3_Pad_Via
J1: Power; Eurorack_Power; mpn 302-S101
J2: IN A; WQP-WQP518MA-skinny; mpn WQP-WQP518MA
J3: OUT A1; WQP-WQP518MA-skinny; mpn WQP-WQP518MA
J4: OUT A2; WQP-WQP518MA-skinny; mpn WQP-WQP518MA
J5: OUT A3; WQP-WQP518MA-skinny; mpn WQP-WQP518MA
J6: OUT A4; WQP-WQP518MA-skinny; mpn WQP-WQP518MA
J7: IN B; WQP-WQP518MA-skinny; mpn WQP-WQP518MA
J8: OUT B1; WQP-WQP518MA-skinny; mpn WQP-WQP518MA
J9: OUT B2; WQP-WQP518MA-skinny; mpn WQP-WQP518MA
J10: OUT B3; WQP-WQP518MA-skinny; mpn WQP-WQP518MA
J11: OUT B4; WQP-WQP518MA-skinny; mpn WQP-WQP518MA
U1, U2: MUX508; TSSOP-16_4.4x5mm_P0.65mm

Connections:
+3V3: BB1.11, BB1.12
+12V: BB1.7, U1.2 (EN), U1.13 (VDD), U2.2 (EN), U2.13 (VDD)
+12VDOWNSTREAM: BB1.3, BB1.5, J1.1 (-12V), J1.2 (-12V)
-12V: BB1.8, U1.3 (VSS), U2.3 (VSS)
-12VDOWNSTREAM: BB1.4, BB1.6, J1.9 (+12V), J1.10 (+12V)
/ADC_1A: BB1.22
/ADC_1B: BB1.21
/ADC_1C: BB1.24
/ADC_1D: BB1.23
/ADC_2A: BB1.36
/ADC_2B: BB1.35
/ADC_2C: BB1.38
/ADC_2D: BB1.37
/ADC_3A: BB1.32
/ADC_3B: BB1.31
/ADC_3C: BB1.34
/ADC_3D: BB1.33
/ADC_4A: BB1.26
/ADC_4B: BB1.25
/ADC_4C: BB1.28
/ADC_4D: BB1.27
/DAC_1A: BB3.32, J2.T (Tip), U1.4 (S1)
/DAC_1B: BB3.31, J7.T (Tip), U1.11 (S6)
/DAC_1C: BB3.34
/DAC_1D: BB3.33
/DAC_2A: BB2.38
/DAC_2B: BB2.37
/DAC_2C: BB2.36
/DAC_2D: BB2.35
/DAC_3A: BB2.34
/DAC_3B: BB2.33
/DAC_3C: BB2.32
/DAC_3D: BB2.31
/DAC_4A: BB3.36
/DAC_4B: BB3.35
/DAC_4C: BB3.38
/DAC_4D: BB3.37
/EXT_AUDIO_A: BB3.7
/EXT_AUDIO_B: BB3.8
/EXT_FG_A: BB3.11
/EXT_FG_B: BB3.12
/EXT_INST_A: BB3.13
/EXT_INST_B: BB3.14
/EXT_INST_C: BB3.16
/EXT_INST_D: BB3.15
/EXT_MM_A: BB3.10
/EXT_MM_V: BB3.9, U1.8 (D)
/EXT_OSC_A: BB3.3
/EXT_OSC_B: BB3.4
/EXT_OSC_C: BB3.6
/EXT_OSC_D: BB3.5
/IO1: BB3.19, U1.1 (A0)
/IO2: BB3.20, U1.16 (A1)
/IO3: BB3.21, U1.15 (A2)
/IO4: BB3.22, U2.1 (A0)
/IO5: BB3.23, U2.16 (A1)
/IO6: BB2.27
/IO7: BB2.21
/IO8: BB2.22
/IO9: BB2.15
/IO10: BB2.16
/IO11: BB2.13
/IO12: BB2.14
/IO13: BB2.9
/IO14: BB2.10
/IO15: BB2.7
/IO16: BB2.8
/IO17: BB2.5
/IO18: BB2.6
/IO19: BB2.3
/IO20: BB1.17
/IO21: BB1.18
/IO22: BB1.15
/IO23: BB1.16
/OUT_A1: J3.T (Tip), U1.5 (S2)
/OUT_A2: J4.T (Tip), U1.6 (S3)
/OUT_A3: J5.T (Tip), U1.7 (S4)
/OUT_A4: J6.T (Tip), U1.12 (S5)
/OUT_B1: J8.T (Tip), U1.10 (S7)
/OUT_B2: J9.T (Tip), U2.4 (S1)
/OUT_B3: J10.T (Tip), U2.5 (S2)
/OUT_B4: J11.T (Tip), U2.6 (S3)
GND: BB1.1, BB1.2, BB1.9, BB1.10, BB1.13, BB1.14, BB1.19, BB1.20, BB1.29, BB1.30, BB1.39, BB1.40, BB2.1, BB2.2, BB2.11, BB2.12, BB2.17, BB2.18, BB2.19, BB2.20, BB2.28, BB2.29, BB2.30, BB2.39, BB2.40, BB3.1, BB3.2, BB3.17, BB3.18, BB3.24, BB3.29, BB3.30, BB3.39, BB3.40, H1.1, H2.1, H3.1, H4.1, J1.3 (GND), J1.4 (GND), J1.5 (GND), J1.6 (GND), J1.7 (GND), J1.8 (GND), J2.S (Sleeve), J3.S (Sleeve), J4.S (Sleeve), J5.S (Sleeve), J6.S (Sleeve), J7.S (Sleeve), J8.S (Sleeve), J9.S (Sleeve), J10.S (Sleeve), J11.S (Sleeve), U1.14 (GND), U2.14 (GND), U2.15 (A2)
unnamed: U1.9 (S8), U2.8 (D)
SERIAL1.0: BB3.28
SERIAL1.1: BB3.27
SERIAL1.2: BB3.26
SERIAL1.3: BB3.25
SERIAL4.0: BB2.24
SERIAL4.1: BB2.23
SERIAL4.2: BB2.26
SERIAL4.3: BB2.25

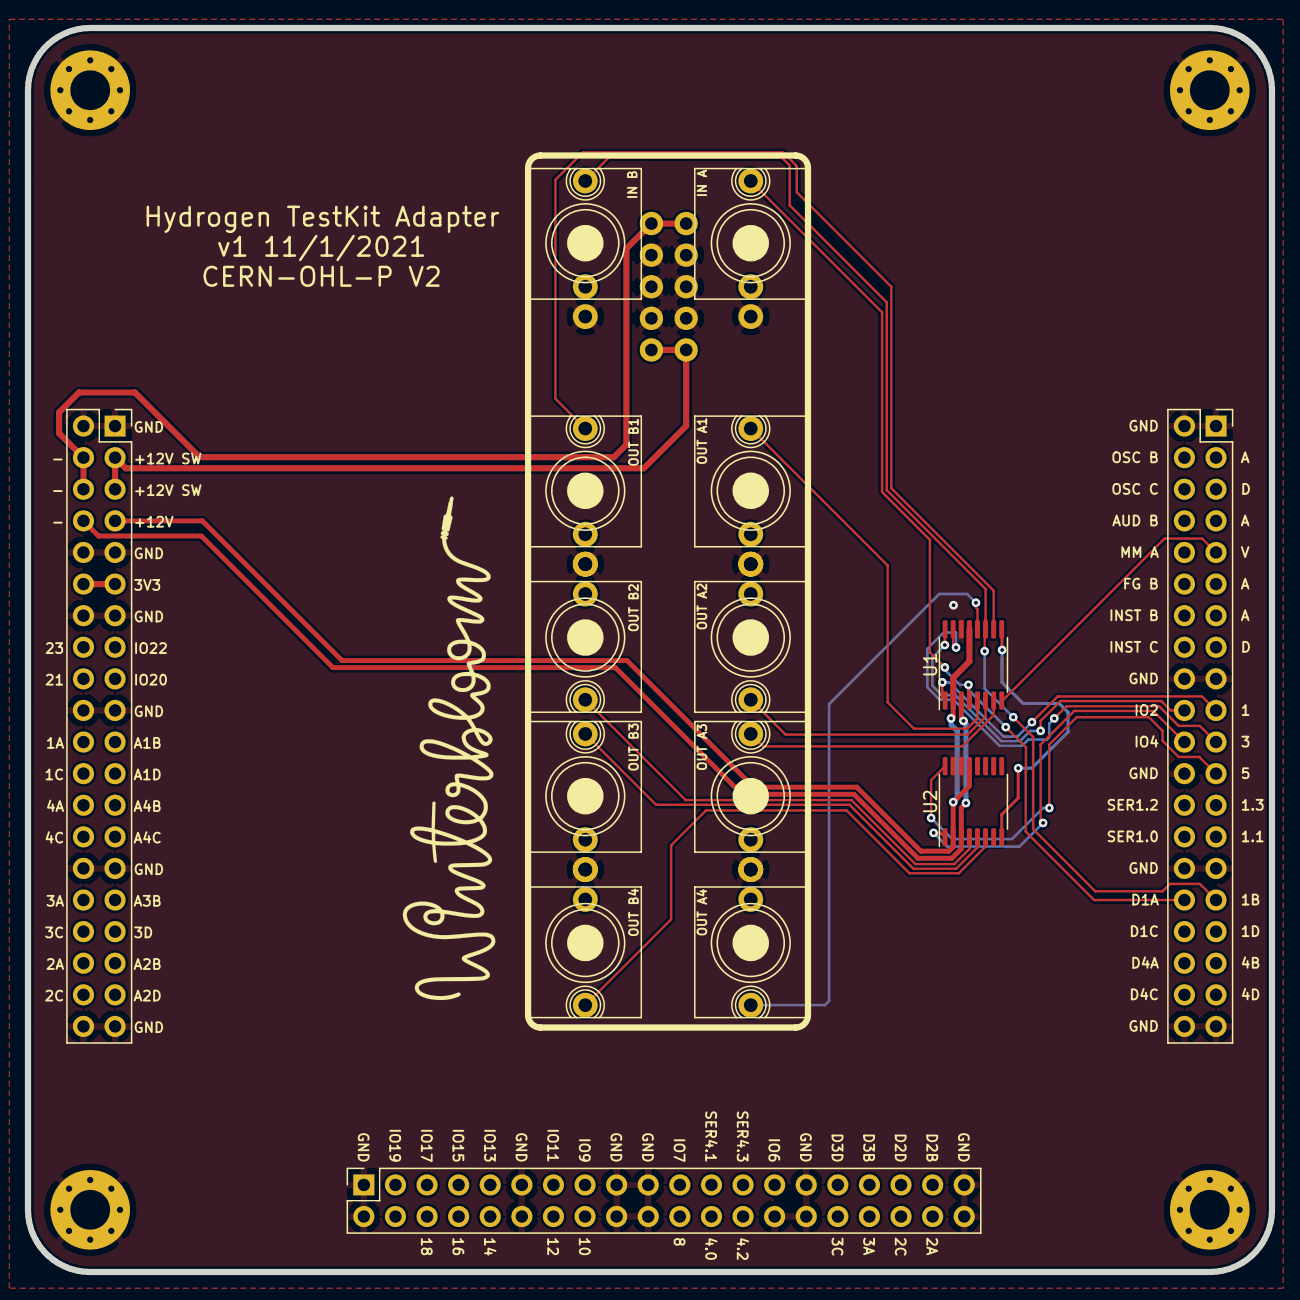
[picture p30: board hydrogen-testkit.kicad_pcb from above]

Board: 2 copper layers, 100.0 x 100.0 mm, 20 parts (1 on the bottom side), 23 nets.

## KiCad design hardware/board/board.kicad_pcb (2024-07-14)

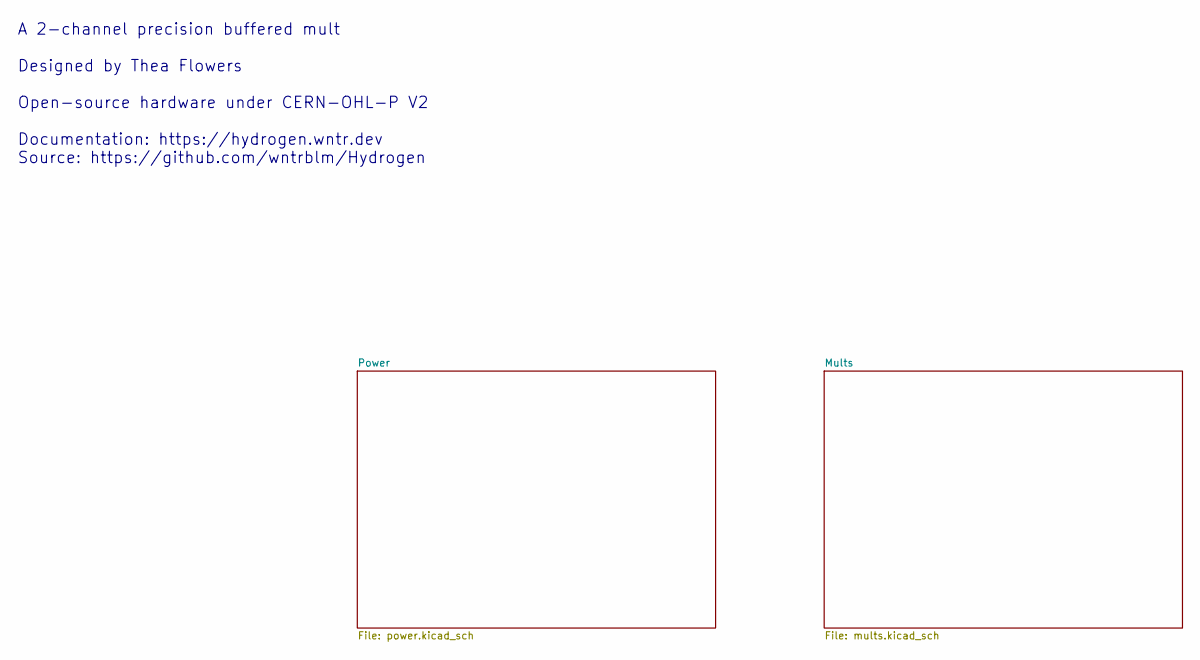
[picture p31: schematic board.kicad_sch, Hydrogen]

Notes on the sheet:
A 2-channel precision buffered mult Designed by Thea Flowers Open-source hardware under CERN-OHL-P V2 Documentation: https://hydrogen.wntr.dev Source: https://github.com/wntrblm/Hydrogen

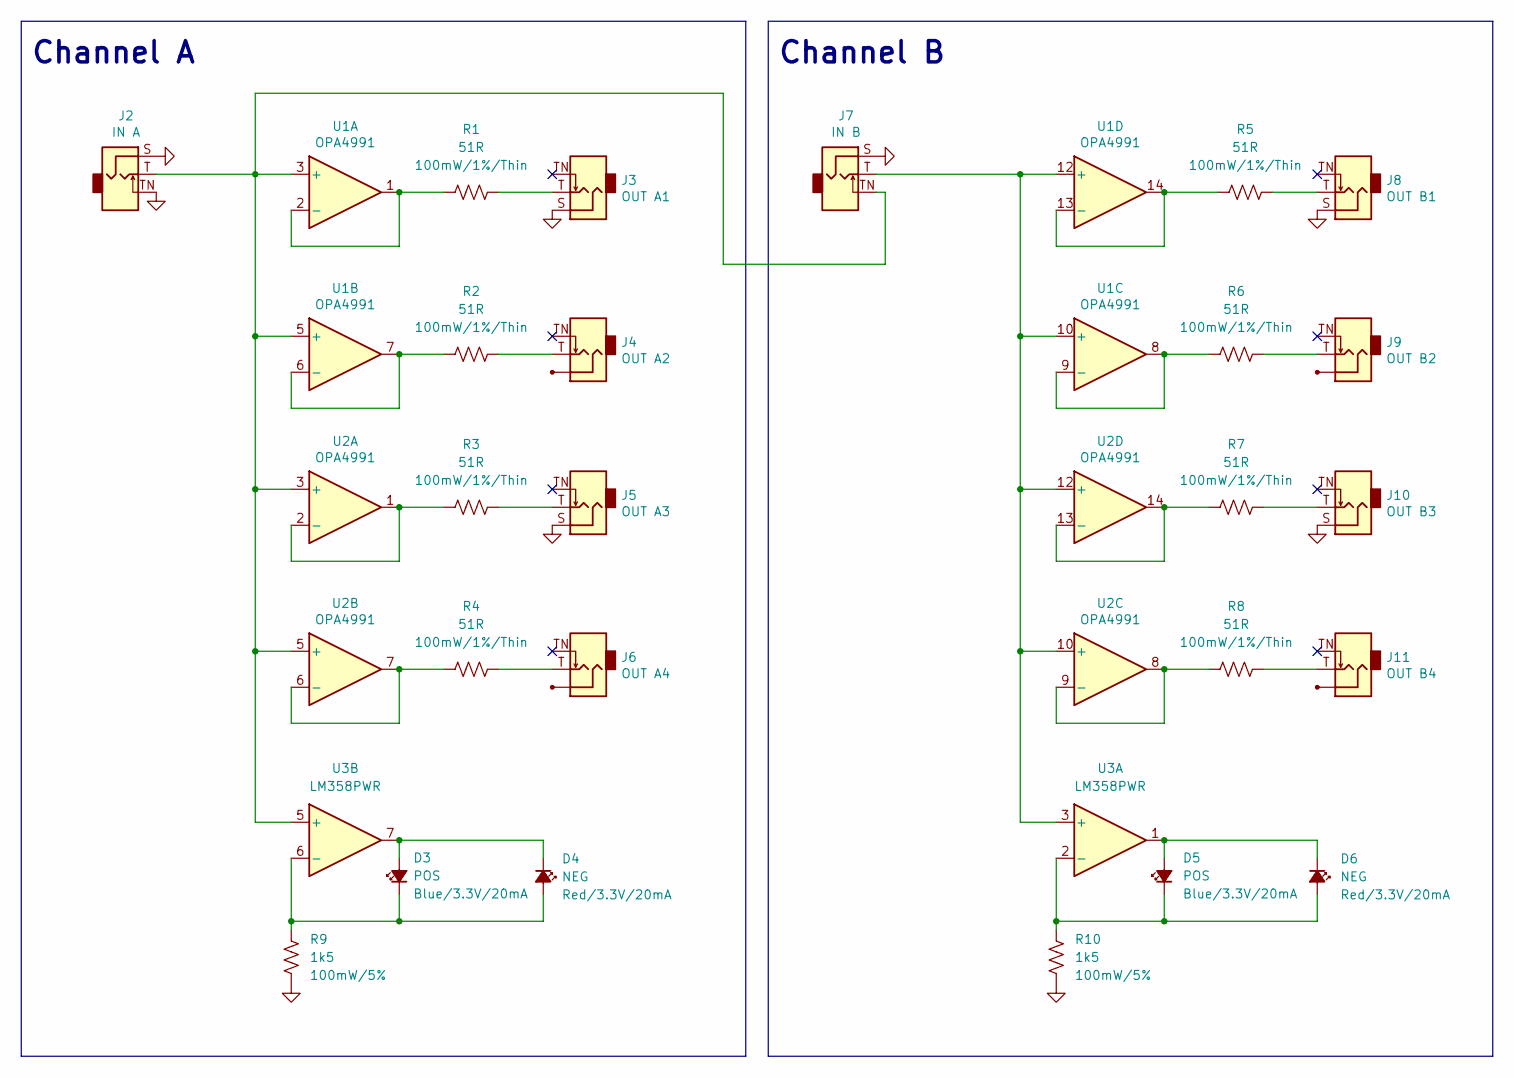
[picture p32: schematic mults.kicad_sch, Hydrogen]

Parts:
D3, D5: POS; LED_0805_Kingbright_APT2012; Rating Blue/3.3V/20mA; MPN APT2012VBC/D; DigiKey 754-1794-1-ND
D4, D6: NEG; LED_0805_Kingbright_APT2012; Rating Red/3.3V/20mA; MPN APT2012SURCK; DigiKey 754-1133-1-ND
J2: IN A; AudioJack_WQP518MA_Compact_S
J3: OUT A1; AudioJack_WQP518MA_Compact_S
J4: OUT A2; AudioJack_WQP518MA_No_S
J5: OUT A3; AudioJack_WQP518MA_Compact_S
J6: OUT A4; AudioJack_WQP518MA_No_S
J7: IN B; AudioJack_WQP518MA_Compact_S
J8: OUT B1; AudioJack_WQP518MA_Compact_S
J9: OUT B2; AudioJack_WQP518MA_No_S
J10: OUT B3; AudioJack_WQP518MA_Compact_S
J11: OUT B4; AudioJack_WQP518MA_No_S
R1, R2, R3, R4, R5, R6, R7, R8: 51R; R_0603_HandSolder; Rating 100mW/1%/Thin; MPN RT0603FRE0751RL; DigiKey 13-RT0603FRE0751RLCT-ND
R9, R10: 1k5; R_0603_HandSolder; Rating 100mW/5%; MPN RC0603JR-071K5L; DigiKey 311-1.5KGRCT-ND
U1, U2: OPA4991; TSSOP-14_4.4x5mm_P0.65mm; MPN OPA4991IPWR; Mouser 595-OPA4991IPWR
U3: LM358PWR; TSSOP-8_4.4x3mm_P0.65mm; MPN LM358PWR; DigiKey 296-OPA4991IPWRCT-ND

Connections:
GND: J2.S (Sleeve), J2.TN (Tip_normalize), J3.S (Sleeve), J5.S (Sleeve), J7.S (Sleeve), J8.S (Sleeve), J10.S (Sleeve), R9.1, R10.1; also elsewhere on the board
unnamed: D3.2 (A), D4.1 (K), U3.7
unnamed: D3.1 (K), D4.2 (A), R9.2, U3.6 (-)
unnamed: D5.2 (A), D6.1 (K), U3.1
unnamed: D5.1 (K), D6.2 (A), R10.2, U3.2 (-)
unnamed: J2.T (Tip), J7.TN (Tip_normalize), U1.3 (+), U1.5 (+), U2.3 (+), U2.5 (+), U3.5 (+)
unnamed: J3.T (Tip), R1.1
unnamed: J4.T (Tip), R2.1
unnamed: J5.T (Tip), R3.1
unnamed: J6.T (Tip), R4.1
unnamed: J7.T (Tip), U1.10 (+), U1.12 (+), U2.10 (+), U2.12 (+), U3.3 (+)
unnamed: J8.T (Tip), R5.1
unnamed: J9.T (Tip), R6.1
unnamed: J10.T (Tip), R7.1
unnamed: J11.T (Tip), R8.1
unnamed: R1.2, U1.1, U1.2 (-)
unnamed: R2.2, U1.6 (-), U1.7
unnamed: R6.2, U1.8, U1.9 (-)
unnamed: R5.2, U1.13 (-), U1.14
unnamed: R3.2, U2.1, U2.2 (-)
unnamed: R4.2, U2.6 (-), U2.7
unnamed: R8.2, U2.8, U2.9 (-)
unnamed: R7.2, U2.13 (-), U2.14

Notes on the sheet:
Channel A
Channel B

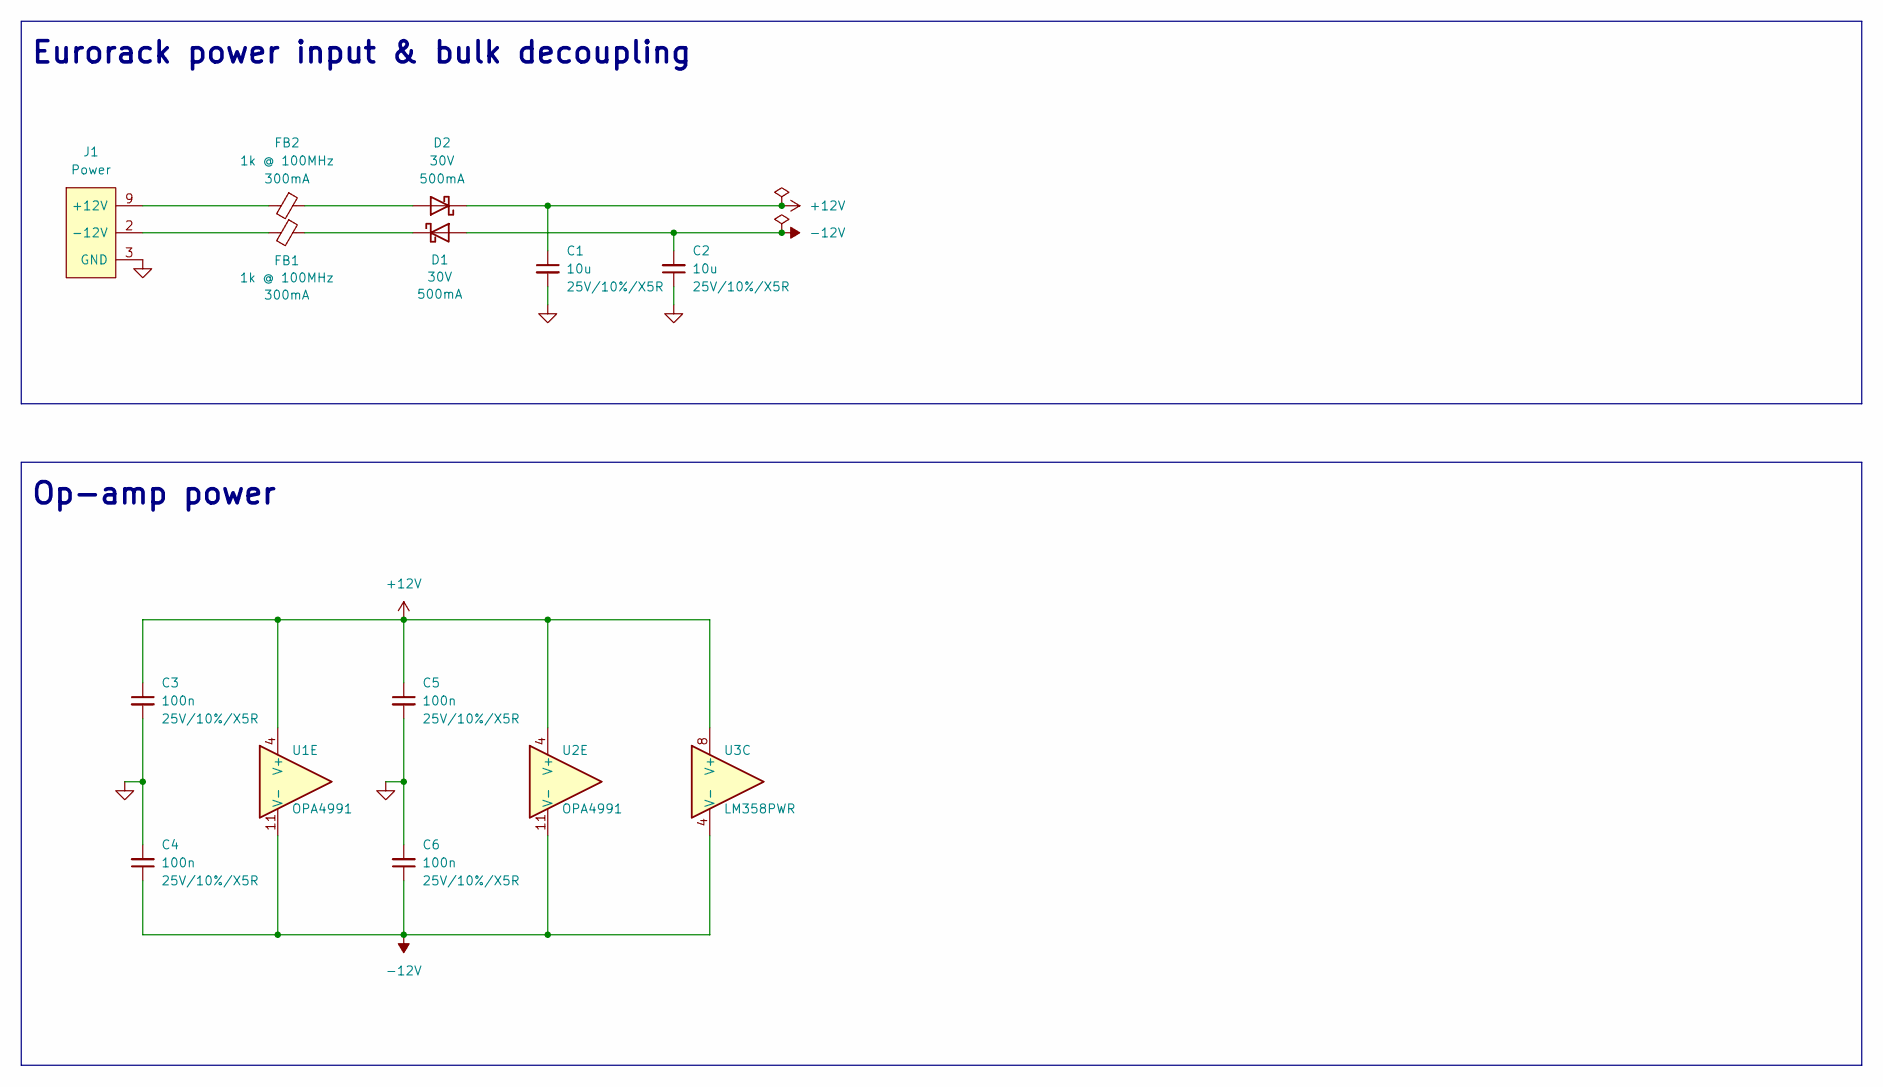
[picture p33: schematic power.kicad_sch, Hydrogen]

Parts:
C1, C2: 10u; C_0805_HandSolder; Rating 25V/10%/X5R; MPN GRM21BR61E106KA73K; DigiKey 490-16824-1-ND
C3, C4, C5, C6: 100n; C_0603_HandSolder; Rating 25V/10%/X5R; MPN CL10B104KB8NNNC; DigiKey 1276-1000-2-ND
D1, D2: 30V; D_SOD-123+SOD-123F; Rating 500mA; MPN PMEG2005EGWX; DigiKey 1727-7329-1-ND
FB1, FB2: 1k @ 100MHz; L_0603_HandSolder; Rating 300mA; MPN BLM18AG102SN1D; DigiKey 490-1015-1-ND
J1: Power; Eurorack_Power_2x5_Shrouded_Lock; MPN 302-S101; DigiKey ED1543-ND
U1, U2: OPA4991; TSSOP-14_4.4x5mm_P0.65mm; MPN OPA4991IPWR; Mouser 595-OPA4991IPWR
U3: LM358PWR; TSSOP-8_4.4x3mm_P0.65mm; MPN LM358PWR; DigiKey 296-OPA4991IPWRCT-ND

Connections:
+12V: C1.1, C3.1, C5.1, D2.1 (K), U1.4 (V+), U2.4 (V+), U3.8 (V+)
-12V: C2.2, C4.1, C6.1, D1.2 (A), U1.11 (V-), U2.11 (V-), U3.4 (V-)
GND: C1.2, C2.1, C3.2, C4.2, C5.2, C6.2, J1.3 (GND), J1.4 (GND), J1.5 (GND), J1.6 (GND), J1.7 (GND), J1.8 (GND); also elsewhere on the board
unnamed: D1.1 (K), FB1.1
unnamed: D2.2 (A), FB2.1
unnamed: FB1.2, J1.1 (-12V), J1.2 (-12V)
unnamed: FB2.2, J1.9 (+12V), J1.10 (+12V)

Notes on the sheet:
Eurorack power input & bulk decoupling
Op-amp power

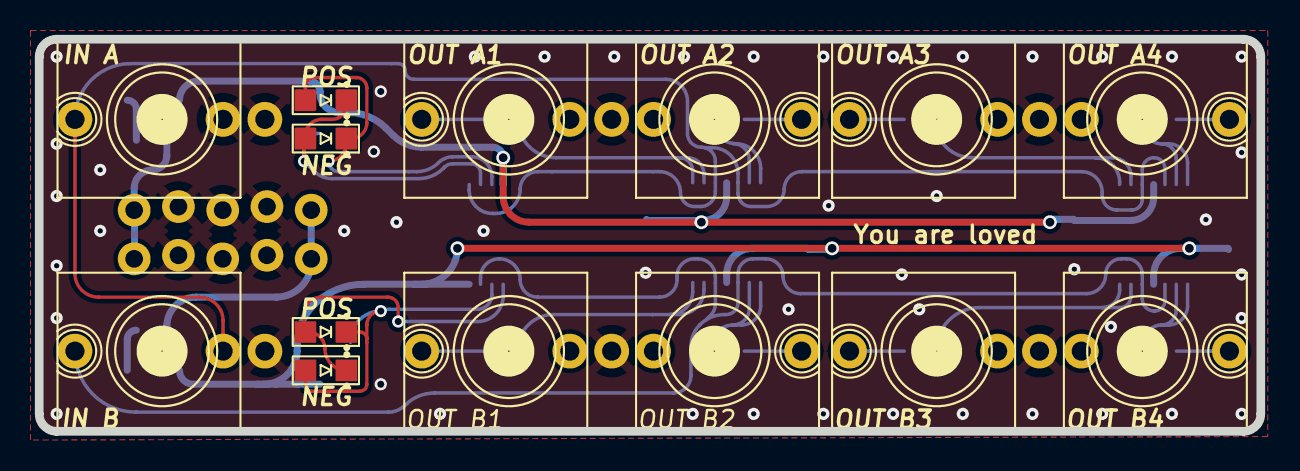
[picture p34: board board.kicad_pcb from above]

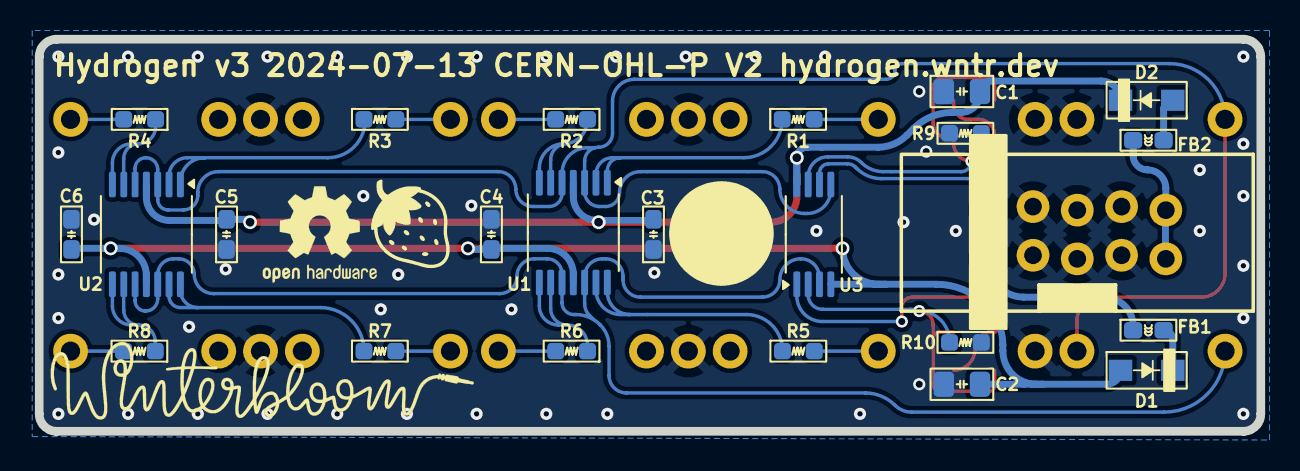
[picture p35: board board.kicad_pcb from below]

Board: 2 copper layers, 70.1 x 22.5 mm, 38 parts (24 on the bottom side), 29 nets.

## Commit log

2021-11-08 Remove Helium's files
    [board.kicad_pcb, board.sch]
2021-11-08 Move Hydrogen files into hardware/
    [board.kicad_pcb, board.sch]
2021-11-08 Add testkit adapter
    [hydrogen-testkit.kicad_pcb, hydrogen-testkit.sch]
2021-11-08 Update resistor values; create PDF
    [board.sch]
2021-11-16 Update resistor values
    [board.kicad_pcb, board.sch]
2021-12-08 hardware: add laser design's for the testkit adapter board guide, pin holder, and pressure plate
2021-12-23 user guide: add basic functionality for the surface mount assembly guide
2021-12-23 hardware: add data to schematic for showing parts in the surface mount assembly guide
    [board.kicad_pcb, board.sch]
2021-12-25 user guide: add surface mount assembly guide
2021-12-25 user guide: move pcbassembly stuff into theme, fixup some stuff.
    [board.kicad_pcb]
2021-12-28 Migrate to KiCAD 6, fix flipped C2
    [board.kicad_pcb, board.kicad_sch]
2021-12-28 Remove old KiCAD 5 files
    [board.sch]
2021-12-28 hardware: update PDF of schematic
2022-01-07 user guide: Add through hole kit build guide
2022-01-11 factory: use wintertools' built in printing functionality
2022-06-19 user guide: link to assembled and kit product pages
2023-01-17 Add design files for light guide
    [light-guide.3mf, light-guide.scad]
2024-02-23 user guide: Switch over to Wintersong theme, remove surface mount kit guide
2024-07-14 Board revision 3
    Schematic:
    - Migrated to new Winterbloom page layout
    - Split into power and mult schematics
    - Updated all symbols
    - Added sourcing information for all items
    PCB:
    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
    [board.kicad_pcb, board.kicad_sch, mults.kicad_sch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]
2024-07-14 hardware: add faceplate
    [faceplate.kicad_pcb]
2024-07-14 hardware: rename testkit-adapter to hubble-lens
    [hydrogen-testkit.kicad_pcb, hydrogen-testkit.sch]

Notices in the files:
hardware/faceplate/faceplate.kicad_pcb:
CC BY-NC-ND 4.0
